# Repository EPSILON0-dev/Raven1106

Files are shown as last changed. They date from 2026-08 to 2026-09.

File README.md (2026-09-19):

# Raven1106

Raspberry Pi-like single board computer based on the Rockchip RV1106G3.

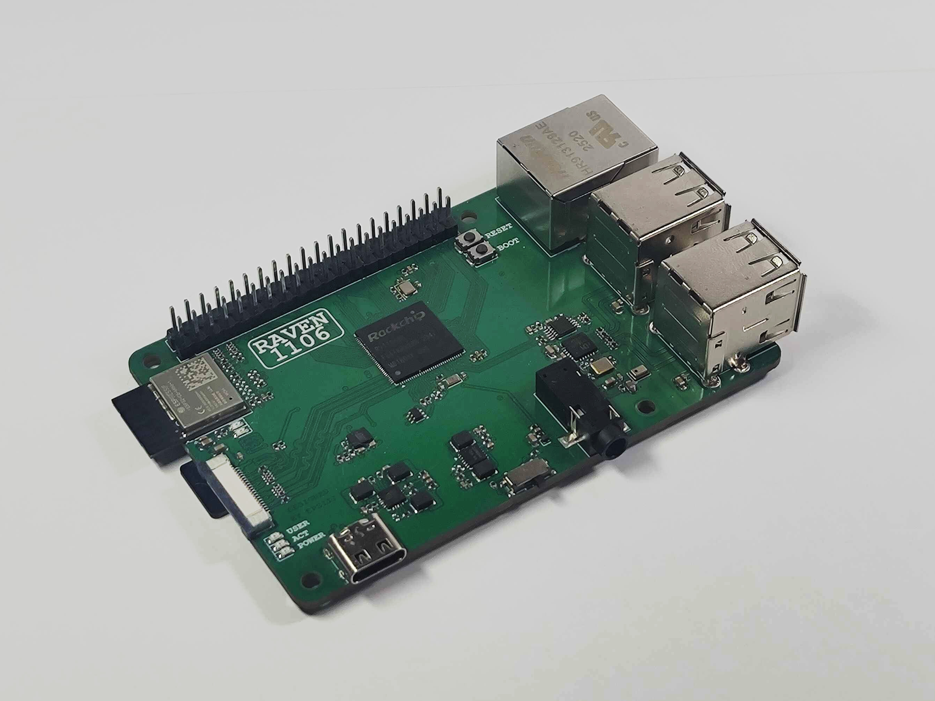
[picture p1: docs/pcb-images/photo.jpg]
Assembled Board Photo


## Overview

Raven1106 is a custom open-hardware SBC. This repository contains everything
related to the project including: the board schematics and the PCB design, build
scripts, configurations, device trees and file system overlays for the 
operating system images and all the patches needed to get everything working.

- CPU: Single-core Cortex-A7 @ 1.6 GHz
- RAM: 256MB DDR3L @ 924MHz
- Storage: SD card
- Ethernet: Full-size 100 MBit/s Ethernet port
- USB: Four USB-A ports routed through CH334F or one OTG USB-C port
- WiFi: ESP32C6 with ESP-Hosted firmware (_currently not functional_)
- Kernel: Linux 5.10 (Rockchip BSP)
- U-Boot: 2017.09 (Rockchip BSP)
- OS images: Debian 12 (bookworm, armhf)

## Why does it exist?

TLDR: It's a learning project

> The main goal of this project was to be a learning experience for designing complex high-speed digital PCBs. Creating an SBC that is almost capable enough to do basic tasks like hosting simple servers or running AI harnesses is a nice bonus. RV1106 was chosen specifically for its simplicity, integrated RAM meant no DDR routing and QFN package meant I could solder the board manually relatively easily. 

> What this chip lacked in the hardware it made up for in the software side of things -- BSP is absolutely terrible, outdated, barely documented (_though with a lot of spelling mistakes_). Programming it wasn't much better either with only a few barely working flashing tools and a USB controller that might not actually be compliant with the USB spec, as most machines can't even enumerate it. It might have been genuinely easier to make this project around a more complex BGA part than this SoC.

## PCB

The board is designed in KiCad (4-layer). `pcb/` contains two revisions:

- `pcb/v1.0` — first revision
- `pcb/v1.1` — revision with component value fixes (no PCB layout changes)

| Layer 1 - Signal | Layer 2 - Ground Plane | Layer 3 - Power Planes | Layer 4 - Signal |
| :-: | :-: | :-: | :-: |
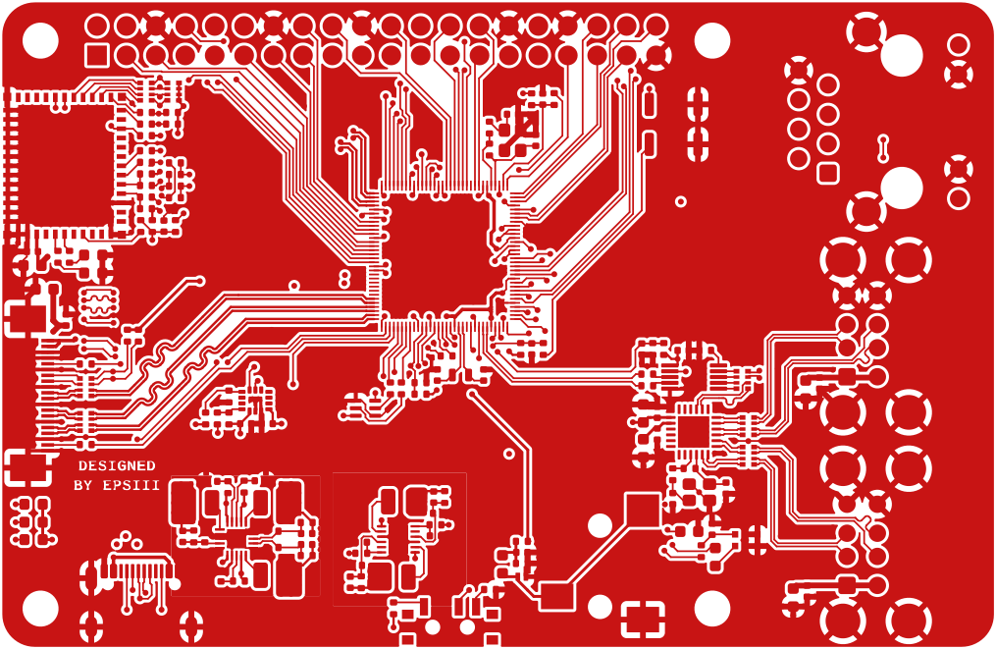
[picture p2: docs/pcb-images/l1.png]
layer1
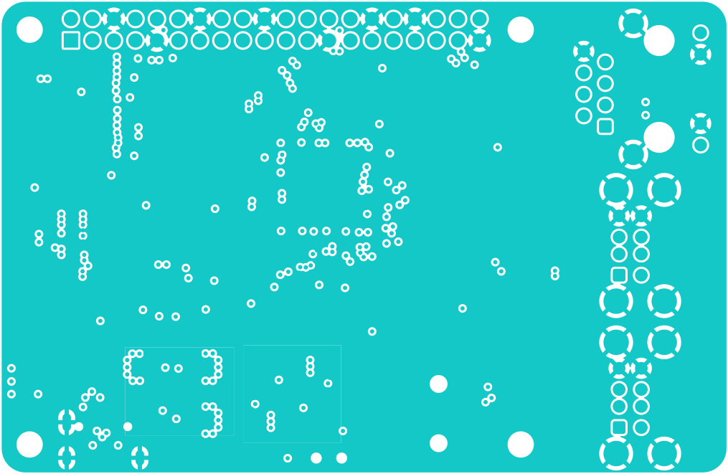
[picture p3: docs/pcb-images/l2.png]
layer2
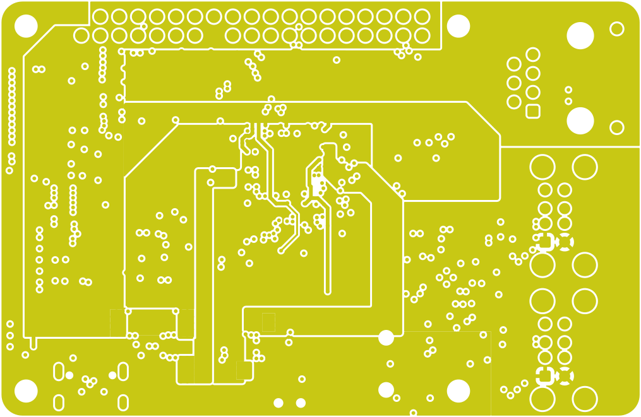
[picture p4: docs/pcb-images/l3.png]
layer3
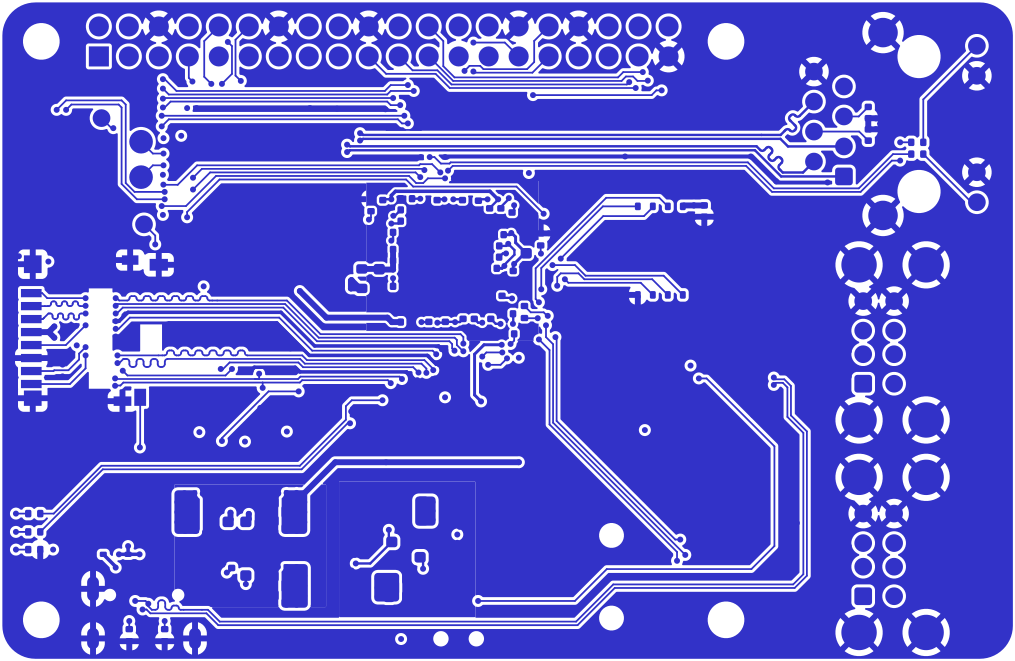
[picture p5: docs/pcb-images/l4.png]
layer4
|  |  |  |  |

### Known v1.0 hardware issues and their fixes

**USB Impedance Miscalculation** - Turns out that FSUSB42MUX doesn't act as a retransmitter but like a normal switch which adds ~10 ohm impedance to the line. **Fix:** Swap `RN301` with 0-ohm and change `R301` and `R302` from 22 ohm to 10 ohm. This results the line impedance that is well in spec.

**No pullups on FSPI Flash** - Speaks for itself, thankfully the RV1106 has internal pull-ups that enable the chip and disable the write protection. And we don't even use it so it's a non-issue. _Cannot fix this without board changes._

**LED resistors too small** - The LEDs shine too brightly with 1k resistors. **Fix:** Change `R3`, `R4` and `R5` from 1k to 10k resistors.

**USB Hub crystal load too large** - The CH334F is designed to work with a crystal with no load caps, adding them causes the oscillation to die down. **Fix:** Change `R309` from 1k to 10 ohm, remove `C302` and `C303`.

**Boot button pull-up too strong** - With 1k the button does not affect the chip's boot at all. **Fix:** Change `R6` from 1k to 10k.

**Wrong ESP_BOOT pin exposed** - It should be pin 9, not pin 8. **Fix:** No way to fix it without modifying the board unfortunately, just flash the bootloader before soldering the ESP.

**Reference clock not connected to the camera** - Turns out not all camera modules have their own crystal oscillators. SC3336 requires a reference clock; RV1106 has two reference clock outputs, one of them is connected to the camera's reset and the other one to the IMU interrupt pin. **Fix:** Add a jumper from `R508` to `R515`.

> Most of these problems could have been prevented with "RTFM" (Reading The F***ing Manual).

## Repository layout

| Path | Contents |
|---|---|
| `configs/` | Defconfigs (kernel, U-Boot, crosstool-ng), device tree source, SD image layout, U-Boot env, user table |
| `kernel/` | Linux 5.10 Rockchip BSP kernel |
| `uboot/` | U-Boot 2017.09 Rockchip BSP |
| `debian/`, `overlayfs/` | Debian rootfs staging area and overlay |
| `crosstool-ng/`, `legacy-toolchain/` | Legacy uClibc toolchain (kernel/U-Boot builds) |
| `esp-hosted/` | ESP32-C6 host driver source (esp_hosted_ng) |
| `rkbin/` | Rockchip binary blobs (DDR init, trust) |
| `scripts/build.sh` | Image assembly, Debian rootfs, Docker environment |
| `images/` | Build artifacts and final `sdcard.img` |
| `pcb/` | KiCad hardware design |
| `docs/` | RV1106 datasheet / reference manuals |

## Building

### Build environment

All builds run inside a Docker container. The first invocation builds the
`rv1106-build` image, then drops you into a shell with the repository
mounted at `/work`:

```sh
make docker
```

### Toolchain

Before building any image build the legacy toolchain for the Kernel and U-Boot.
```sh
make toolchain
```

### Debian image

```sh
make            # default target: debian-image
# or explicitly:
make debian-image
```

> Known issue: If build fails on stage 2 debootstrap because of "Invalid format", just delete the `debian/` directory, restart the container and try to build again. _It does that sometimes..._

This builds the kernel, device tree, and U-Boot, then creates a Debian 12
(bookworm, armhf) rootfs with debootstrap (using qemu-user-static/binfmt for
the second stage) and assembles `images/sdcard.img`.

Notes:

- Default login: user `debian`, password `raven` (sudo user, SSH enabled).
  Override with the `BOARD_USER` and `DEBIAN_PASSWORD` environment variables.
- Included packages: systemd, ifupdown, openssh-server, sudo, dhcp client,
  busybox, vim-tiny, ca-certificates (see `DEBIAN_PACKAGES` in
  `scripts/build.sh`).
- Rootfs image size: 1 GB (`DEBIAN_ROOTFS_SIZE`).
- For now there's no autoresize, run `sudo resize2fs /dev/mmcblk1p5` after
  the first boot.

### Component targets

| Target | Description |
|---|---|
| `make kernel` | Build the kernel using the legacy toolchain |
| `make dtb` | Preprocess and compile `configs/device-tree.dts` into `images/` |
| `make uboot` | Build U-Boot (SPL + idblock + uboot.img) |
| `make espdriver` | Build the ESP32-C6 host driver against the kernel |
| `make toolchain` | Build the crosstool-ng uClibc toolchain |
| `make docker` | Build/enter the Docker build environment |
| `make *-clean` | Clean kernel / U-Boot build trees |

### Configuration targets

Each of these copies the stored defconfig from `configs/`, opens
`menuconfig`, and saves the result back to `configs/`:

```sh
make kernel-config
make uboot-config
make toolchain-config
```

## Output artifacts

All artifacts land in `images/`:

| File | Description |
|---|---|
| `sdcard.img` | Final flashable SD card image |
| `download.bin`, `idblock.img`, `uboot.img` | Bootloader stages |
| `Image`, `zImage`, `device-tree.dtb` | Kernel and device tree |
| `env.img` | U-Boot environment (from `configs/image-env.txt`) |
| `boot.vfat` | FAT32 boot partition (kernel + dtb) |
| `rootfs.ext4`, `rootfs.tar` | Root filesystem |

### SD card layout

The image has no MBR/GPT; partitions are defined by the kernel command line
(`blkdevparts`, see `configs/sdcard-image.cfg` and `configs/image-env.txt`):

| Partition | Offset | Size | Contents |
|---|---|---|---|
| env | 0x0 | 32 KiB | U-Boot environment |
| idblock | 0x8000 | 512 KiB | Rockchip ID block (SPL) |
| uboot | 0x88000 | 256 KiB | U-Boot |
| boot | 4 MiB | 64 MiB | FAT32: kernel image + device tree |
| rootfs | 68 MiB | remainder | ext4 root filesystem |

## Flashing and first boot

```sh
sudo dd if=images/sdcard.img of=/dev/sdX bs=4M status=progress conv=fsync
```

Serial console: `ttyFIQ0` at 115200 baud.

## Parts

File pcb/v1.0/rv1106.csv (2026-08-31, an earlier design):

Reference | Qty | Value | DNP | Footprint | LCSC
C1,C2,C3,C4,C302,C303 | 6 | 18p |  | Capacitor_SMD:C_0402_1005Metric | C7393840
C5 | 1 | 1n |  | Capacitor_SMD:C_0402_1005Metric | C6119789
C6 | 1 | 10n |  | Capacitor_SMD:C_0402_1005Metric | C696856
C101,C106 | 2 | DNP | DNP | Capacitor_SMD:C_0402_1005Metric
C102,C103,C104,C109,C113,C114,C115,C116,C117,C118,C119,C122,C123,C126,C127,C131,C146,C203,C307,C309,C311,C314,C402,C502,C503,C507 | 26 | 10u 6.3V |  | Capacitor_SMD:C_0603_1608Metric | C1691
C105,C107,C108,C124,C125,C129,C130,C132,C133,C134,C135,C136,C137,C138,C139,C140,C141,C142,C143,C144,C145,C147,C149,C150,C152,C154,C156,C157,C158,C202,C301,C304,C305,C306,C308,C310,C312,C313,C403,C501,C504,C505,C506 | 43 | 100n |  | Capacitor_SMD:C_0402_1005Metric | C3839219
C110,C111,C112,C120,C121 | 5 | 220p |  | Capacitor_SMD:C_0402_1005Metric | C50323515
C128,C153,C401,C508 | 4 | 1u |  | Capacitor_SMD:C_0402_1005Metric | C380293
C201 | 1 | 100n | DNP | Capacitor_SMD:C_0402_1005Metric | C3839219
D1 | 1 | POWER |  | LED_SMD:LED_0603_1608Metric
D2 | 1 | ACT |  | LED_SMD:LED_0603_1608Metric
D3 | 1 | USER |  | LED_SMD:LED_0603_1608Metric
D201 | 1 | BAT60A |  | Diode_SMD:D_SOD-323 | C5355496
D401 | 1 | ESP_LED0 |  | LED_SMD:LED_0603_1608Metric
D402 | 1 | ESP_LED1 |  | LED_SMD:LED_0603_1608Metric
D501 | 1 | PESD3V3S1UL |  | Diode_SMD:D_SOD-882 | C70371
J1 | 1 | GPIO |  | Connector_PinHeader_2.54mm:PinHeader_2x20_P2.54mm_Vertical
J201 | 1 | Micro_SD_Card_Det1 |  | Connector_Card:microSD_HC_Hirose_DM3D-SF | C719027
J301 | 1 | USB_C_Receptacle_USB2.0_14P |  | Connector_USB:USB_C_Receptacle_G-Switch_GT-USB-7010ASV
J302 | 1 | HR913129AE |  | Connector_RJ:RJ45_Hanrun_HR911105A_Horizontal | C95663
J303,J304 | 2 | USB_A_Stacked |  | Connector_USB:USB_A_Wuerth_61400826021_Horizontal_Stacked | C456021
J501 | 1 | AudioJack |  | Connector_Audio:Jack_3.5mm_CUI_SJ-3523-SMT_Horizontal | C4991872
J502 | 1 | Camera |  | FPC_Connector:FPC_20_0.5mm_MP_BottomSide | C51364851
L101,L102,L103,L104,L105 | 5 | 1u5 |  | Inductor_SMD:L_1008_2520Metric | C53514831
MIC501 | 1 | MSM421ACT006 |  | Microphone:LGA4-1.9x2.8 | C51928207
Q501 | 1 | FDG1024NZ |  | Package_TO_SOT_SMD:SOT-363_SC-70-6 | C51886163
R1 | 1 | 1M |  | Resistor_SMD:R_0402_1005Metric | C3017524
R2,R205,R301,R302,R412,R413,R416,R417,R418,R419,R508,R515,R516 | 13 | 22 |  | Resistor_SMD:R_0402_1005Metric | C2929994
R3,R4,R5,R6,R8,R303,R307,R308,R309,R311,R312,R403 | 12 | 1k |  | Resistor_SMD:R_0402_1005Metric | C54531013
R7,R9,R402,R404,R503,R505,R509 | 7 | 100 |  | Resistor_SMD:R_0402_1005Metric | C54920716
R101,R103,R201,R313,R401,R406,R407,R420,R421,R501,R507,R510,R511,R512,R513 | 15 | 10k |  | Resistor_SMD:R_0402_1005Metric | C54531014
R102,R104 | 2 | 100k |  | Resistor_SMD:R_0402_1005Metric | C53224176
R105 | 1 | 200k |  | Resistor_SMD:R_0402_1005Metric | C54920643
R106,R107,R112,R113 | 4 | 100k 1% |  | Resistor_SMD:R_0402_1005Metric | C53224176
R108 | 1 | 9.1k 1% |  | Resistor_SMD:R_0402_1005Metric | C54920711
R109,R114 | 2 | 47k 1% |  | Resistor_SMD:R_0402_1005Metric | C18222281
R110 | 1 | 200k 1% |  | Resistor_SMD:R_0402_1005Metric | C54920643
R111 | 1 | 40.2k 1% |  | Resistor_SMD:R_0402_1005Metric | C25893
R115 | 1 | 127k 1% |  | Resistor_SMD:R_0402_1005Metric | C48391434
R116 | 1 | 240 1% |  | Resistor_SMD:R_0402_1005Metric | C2909339
R117 | 1 | 0 (0603) |  | Resistor_SMD:R_0603_1608Metric | C53224183
R202,R502 | 2 | 0 | DNP | Resistor_SMD:R_0402_1005Metric
R304,R306 | 2 | 5k1 |  | Resistor_SMD:R_0402_1005Metric | C53224182
R305 | 1 | 6.04k 1% |  | Resistor_SMD:R_0402_1005Metric | C881060
R310 | 1 | 1M | DNP | Resistor_SMD:R_0402_1005Metric
R314 | 1 | 18k |  | Resistor_SMD:R_0402_1005Metric | C49653003
R408,R409,R506 | 3 | 10k | DNP | Resistor_SMD:R_0402_1005Metric
R410,R411,R414,R415 | 4 | 22 | DNP | Resistor_SMD:R_0402_1005Metric
RN301,RN302,RN303,RN402,RN501,RN502 | 6 | 22 |  | Resistor_SMD:R_Array_Convex_4x0402 | C168184
RN401 | 1 | 10k |  | Resistor_SMD:R_Array_Convex_4x0402 | C168183
SW1 | 1 | Boot |  | Button_Switch_SMD:SW_Push_SPST_NO_Alps_SKRK
SW2 | 1 | Reset |  | Button_Switch_SMD:SW_Push_SPST_NO_Alps_SKRK
SW301 | 1 | USB_Select |  | Button_Switch_SMD:SW_SPDT_PCM12
TP401 | 1 | ESP_Boot |  | TestPoint:TestPoint_Pad_D1.5mm
TP402 | 1 | ESP_Reset |  | TestPoint:TestPoint_Pad_D1.5mm
TP404 | 1 | ESP_USBM |  | TestPoint:TestPoint_Pad_D2.0mm
TP405 | 1 | ESP_USBP |  | TestPoint:TestPoint_Pad_D2.0mm
U1 | 1 | RV1106G3 |  | library:Rockchip_QFN-128-1EP_12.3x12.3mm_P0.35mm_EP7x7mm
U101 | 1 | EA3036CQB |  | Package_DFN_QFN:QFN-20-1EP_3x3mm_P0.4mm_EP1.65x1.65mm | C570857
U102 | 1 | PAM2306AYPAA |  | Package_DFN_QFN:WDFN-12-1EP_3x3mm_P0.45mm_EP1.7x2.5mm | C508237
U202 | 1 | Flash | DNP | Package_SON:WSON-8-1EP_8x6mm_P1.27mm_EP3.4x4.3mm
U302 | 1 | FSUSB42MUX |  | Package_SO:MSOP-10_3x3mm_P0.5mm | C11355
U303 | 1 | CH334F |  | Package_DFN_QFN:QFN-24-1EP_4x4mm_P0.5mm_EP2.7x2.7mm | C5187527
U402 | 1 | ESP32-C6-MINI-1 |  | RF_Module:ESP32-C6-MINI-1
U501 | 1 | LSM6DSR |  | Package_LGA:LGA-14_3x2.5mm_P0.5mm_LayoutBorder3x4y
Y1 | 1 | 32.768kHz |  | Crystal:Crystal_SMD_2012-2Pin_2.0x1.2mm | C2961989
Y2 | 1 | 24MHz 20ppm |  | Crystal:Crystal_SMD_2520-4Pin_2.5x2.0mm | C5261113
Y301 | 1 | 12MHz |  | Crystal:Crystal_SMD_2520-4Pin_2.5x2.0mm | C5261113

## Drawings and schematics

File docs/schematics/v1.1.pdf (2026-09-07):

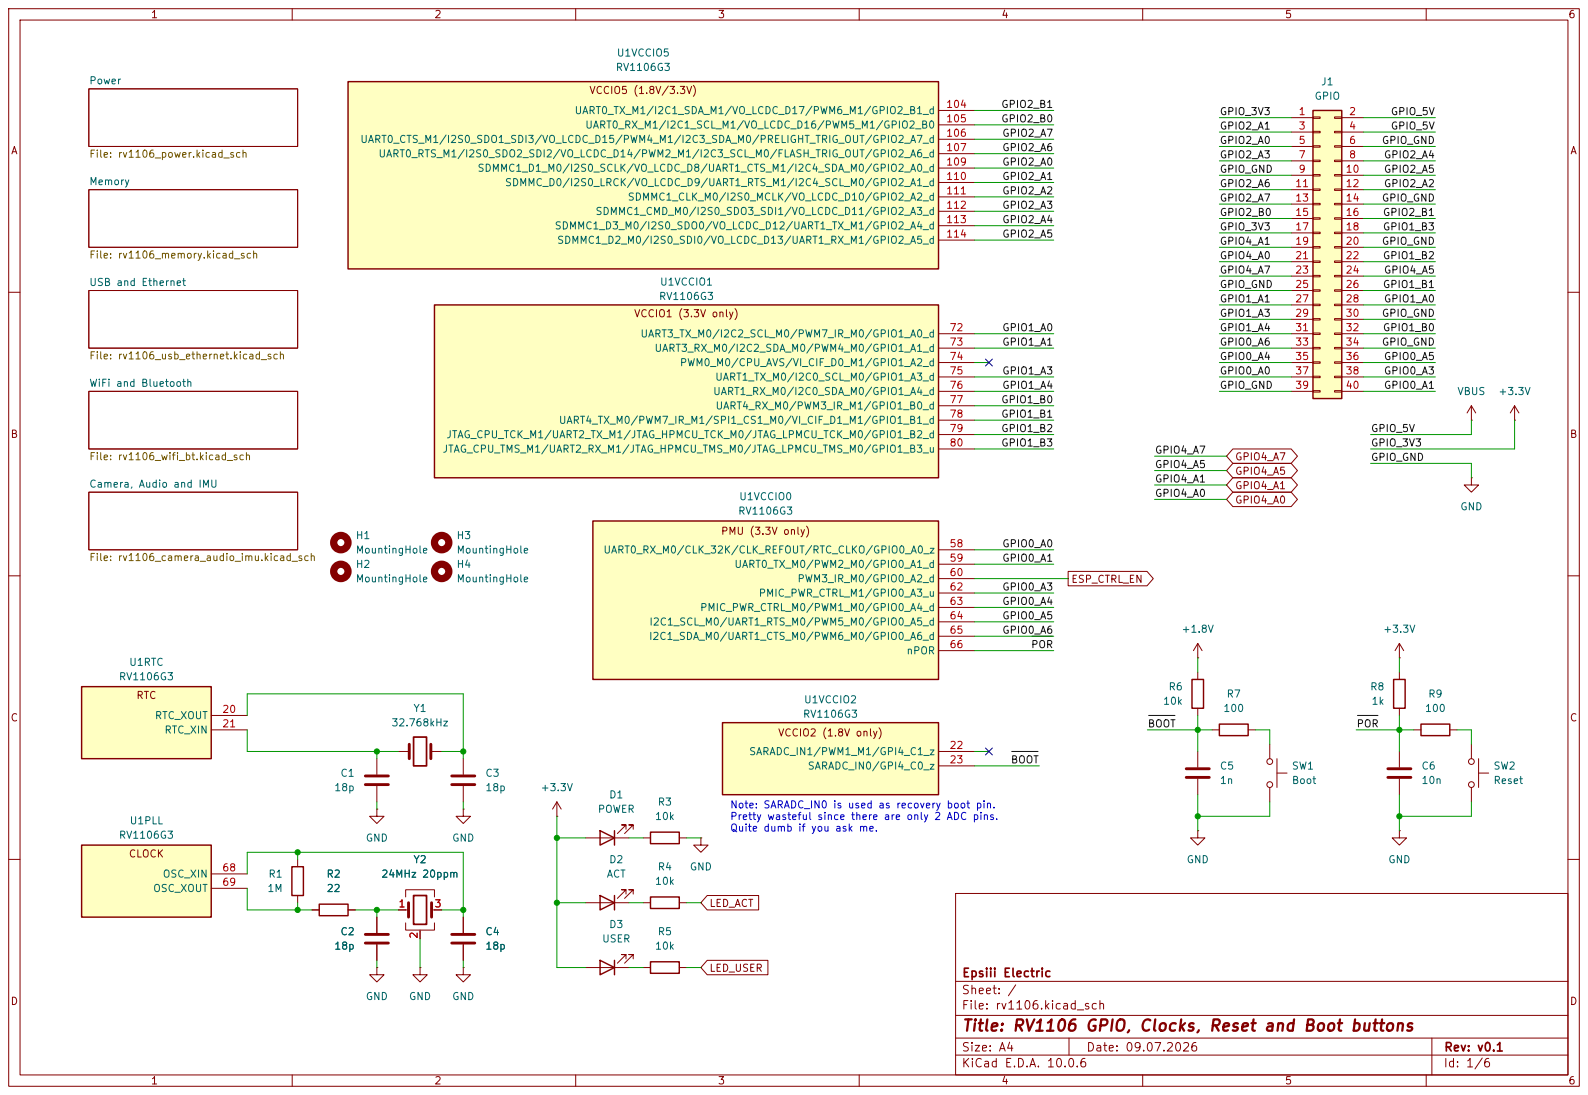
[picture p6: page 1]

File: rv1106_camera_audio_imu.kicad_sch USB and Ethernet File: rv1106_usb_ethernet.kicad_sch Memory File: rv1106_memory.kicad_sch WiFi and Bluetooth

Camera, Audio and IMU

Pretty wasteful since there are only 2 ADC pins. Quite dumb if you ask me. C4

Epsiii Electric
Sheet: /
File: rv1106.kicad_sch
Title: RV1106 GPIO, Clocks, Reset and Boot buttons

Size: A4 | Rev: v0.1
KiCad E.D.A. 10.0.6 | Id: 1/6

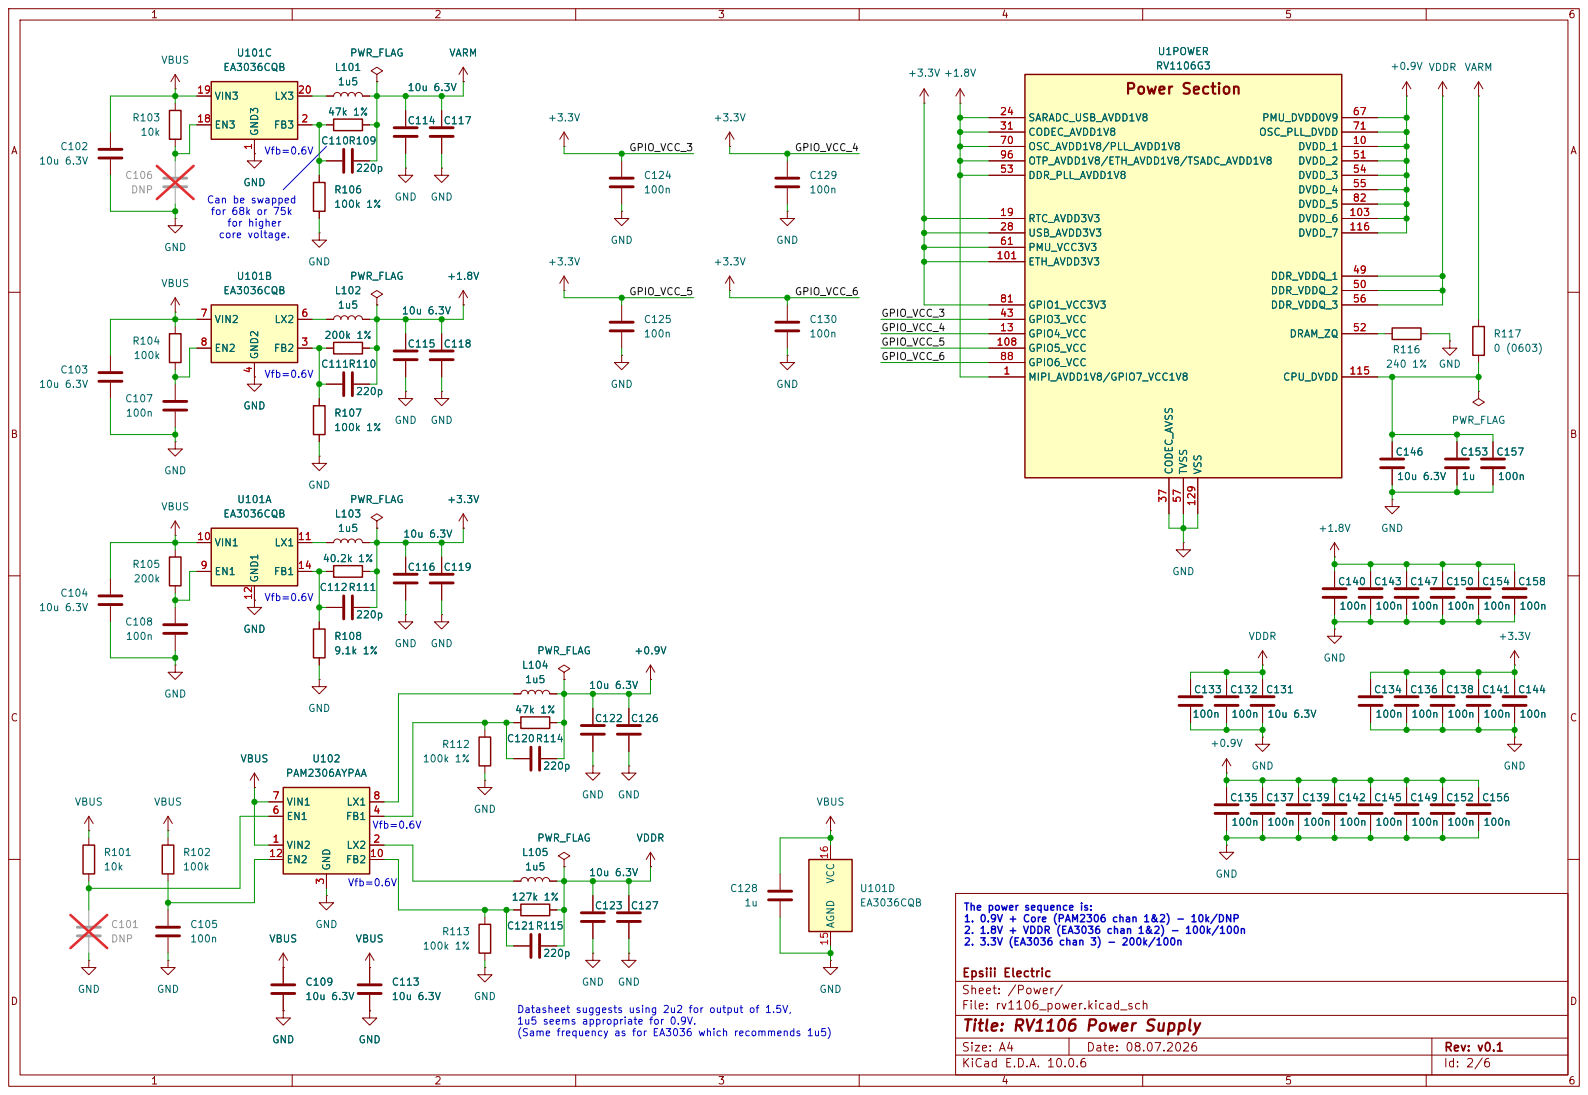
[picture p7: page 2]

Vfb=0.6V Can be swapped

for 68k or 75k
for higher core voltage.

The power sequence is: 1. 0.9V + Core (PAM2306 chan 1&2) - 10k/DNP

2. 1.8V + VDDR (EA3036 chan 1&2) - 100k/100n 2. 3.3V (EA3036 chan 3) - 200k/100n Datasheet suggests using 2u2 for output of 1.5V, 1u5 seems appropriate for 0.9V. (Same frequency as for EA3036 which recommends 1u5)

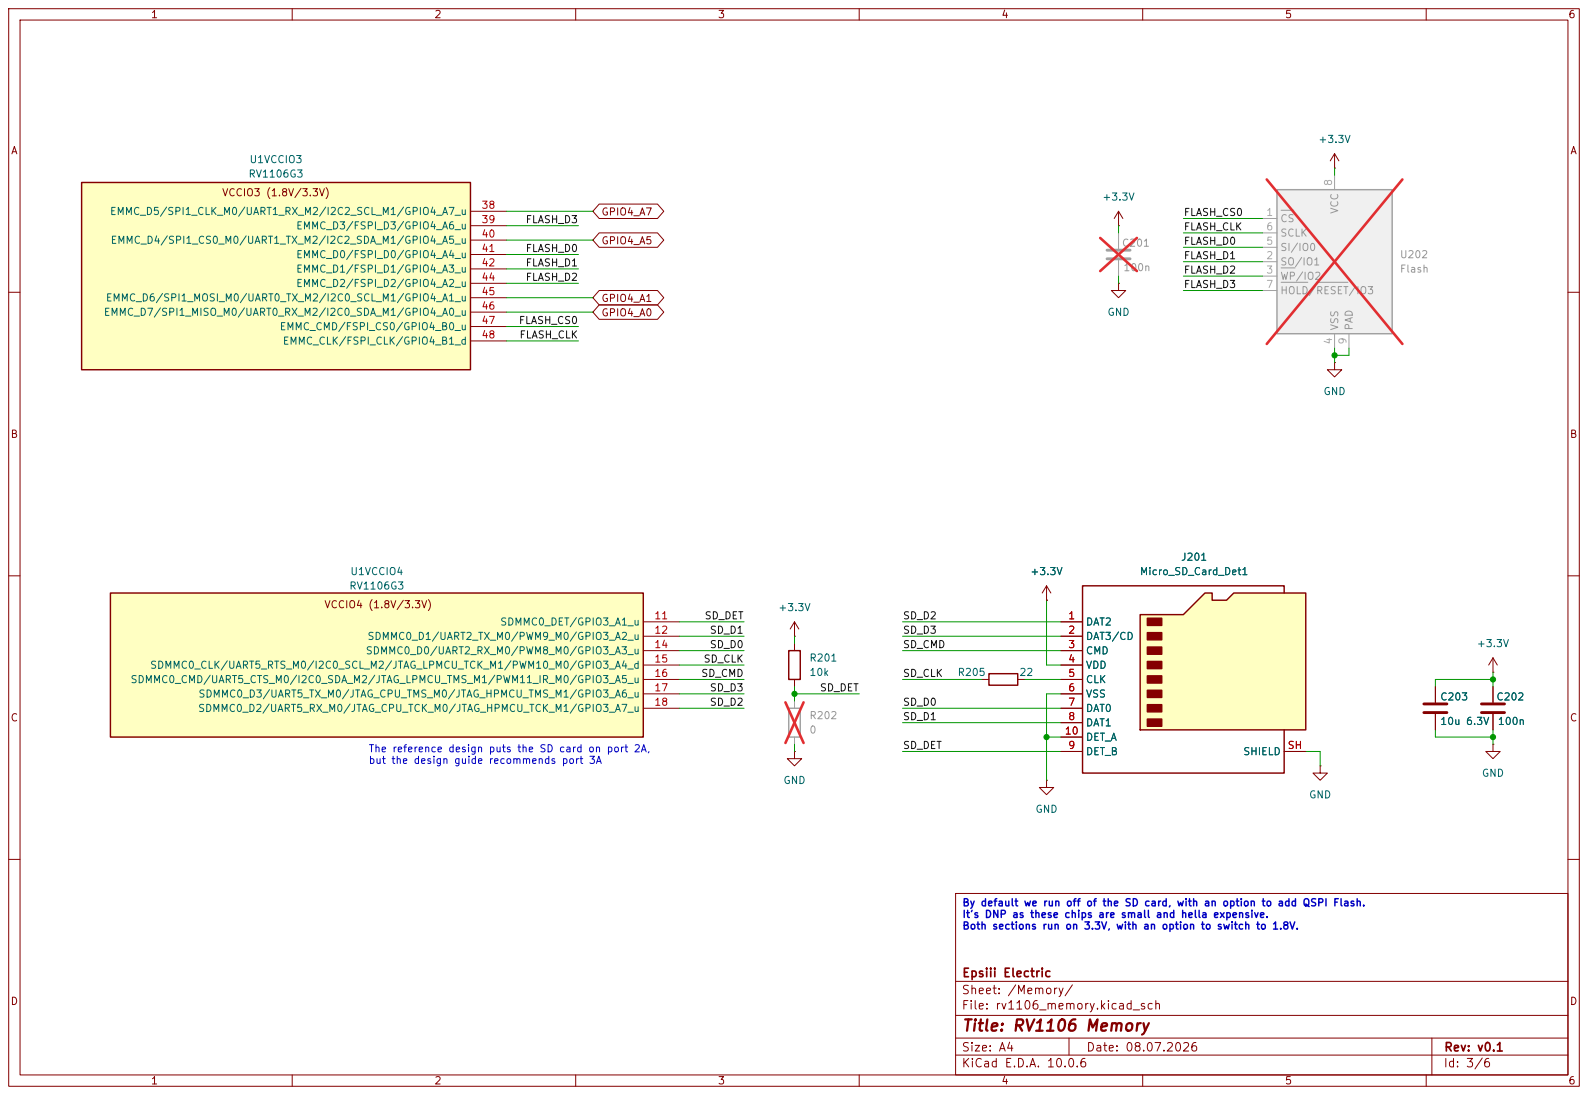
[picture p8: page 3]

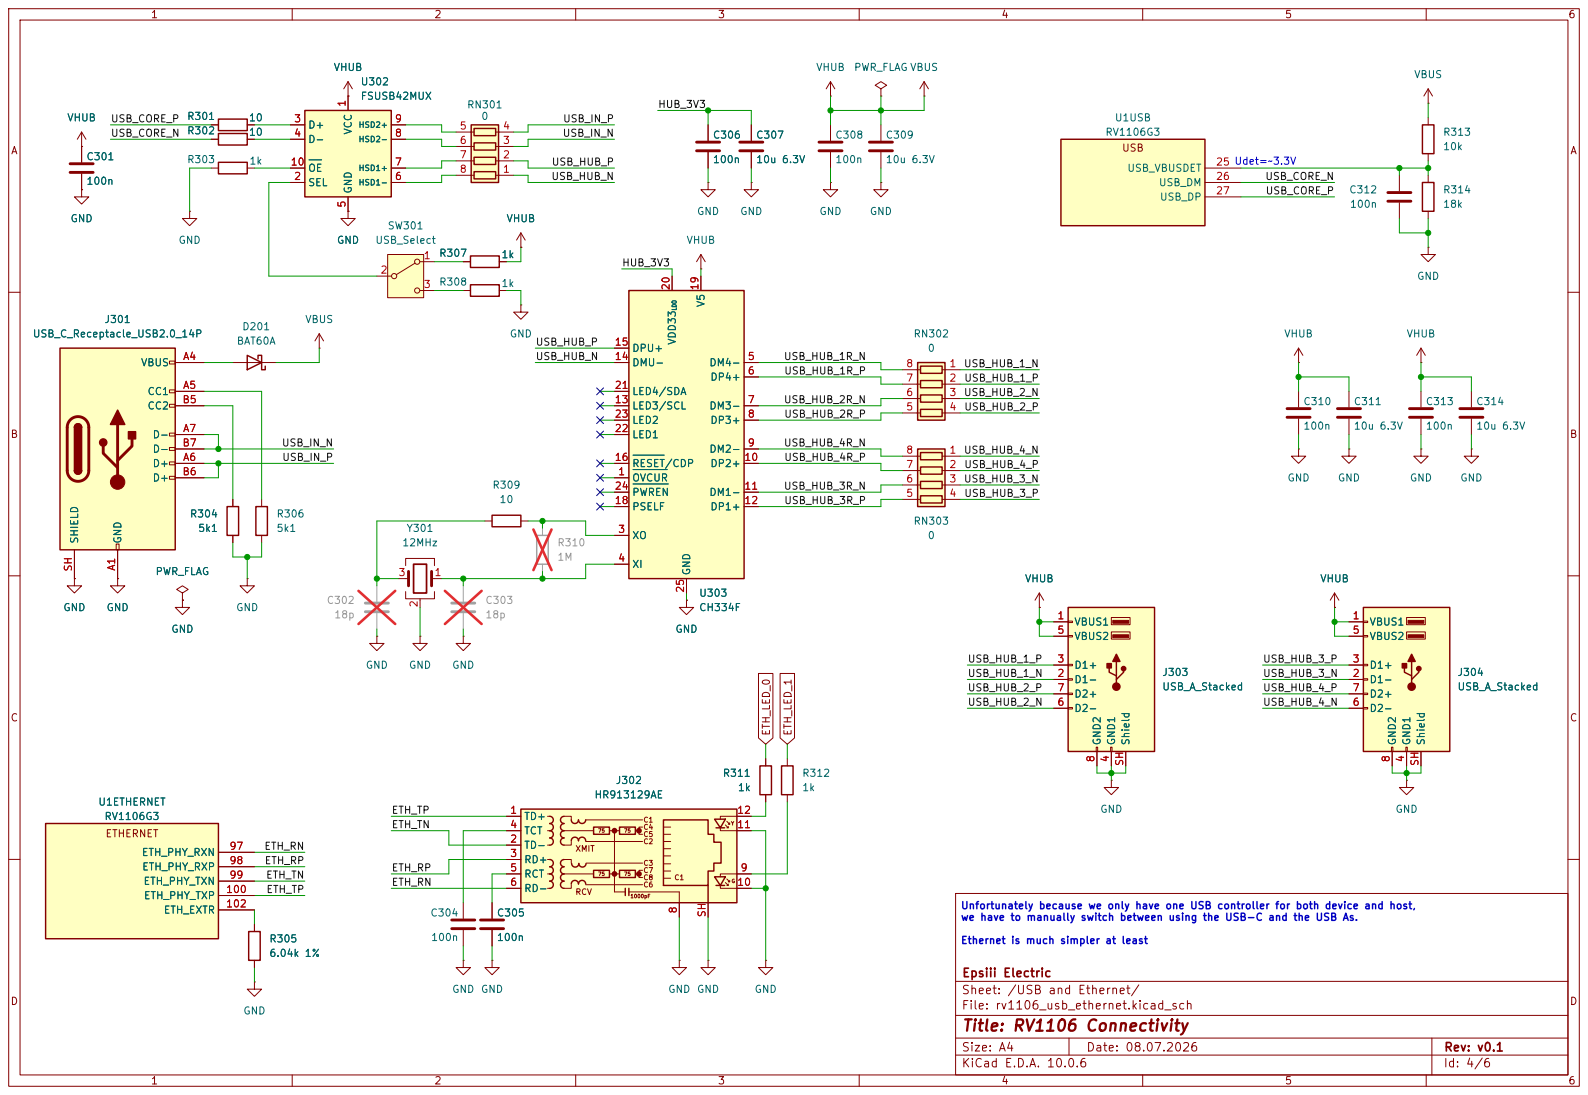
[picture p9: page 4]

Epsiii Electric
Sheet: /USB and Ethernet/
File: rv1106_usb_ethernet.kicad_sch
Title: RV1106 Connectivity

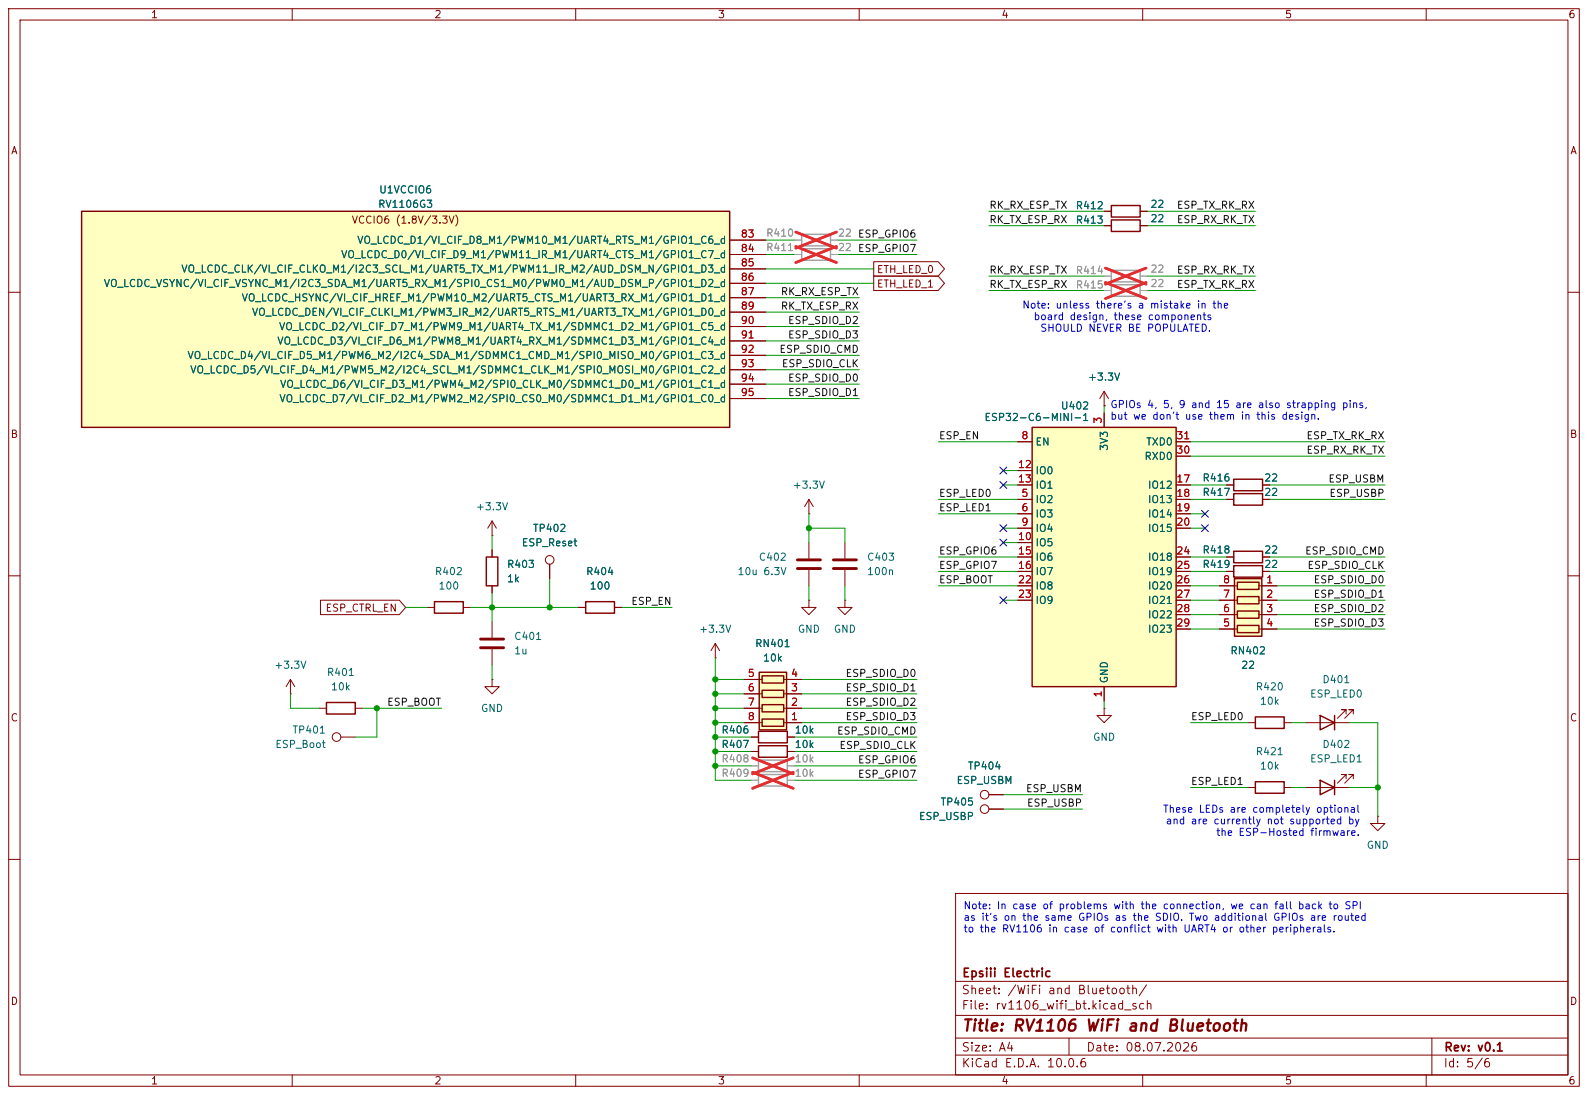
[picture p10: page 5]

to the RV1106 in case of conflict with UART4 or other peripherals. These LEDs are completely optional and are currently not supported by

Epsiii Electric
Sheet: /WiFi and Bluetooth/
File: rv1106_wifi_bt.kicad_sch
Title: RV1106 WiFi and Bluetooth

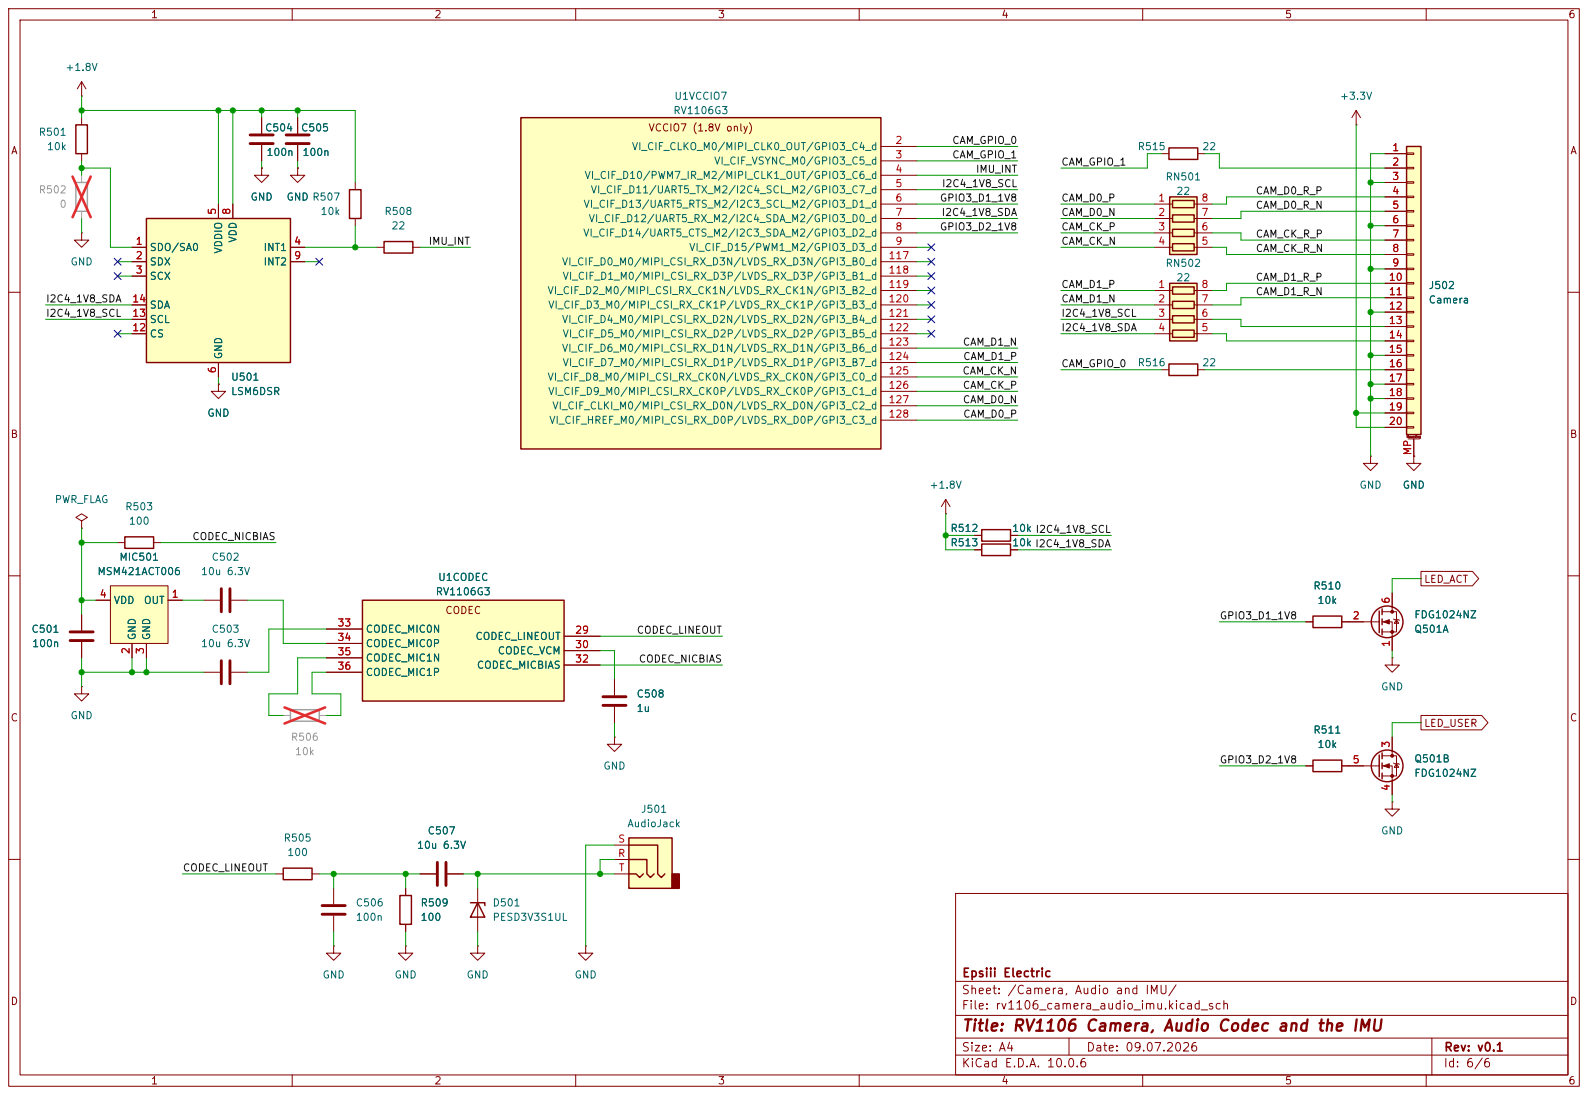
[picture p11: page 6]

Sheet: /Camera, Audio and IMU/
File: rv1106_camera_audio_imu.kicad_sch
Title: RV1106 Camera, Audio Codec and the IMU

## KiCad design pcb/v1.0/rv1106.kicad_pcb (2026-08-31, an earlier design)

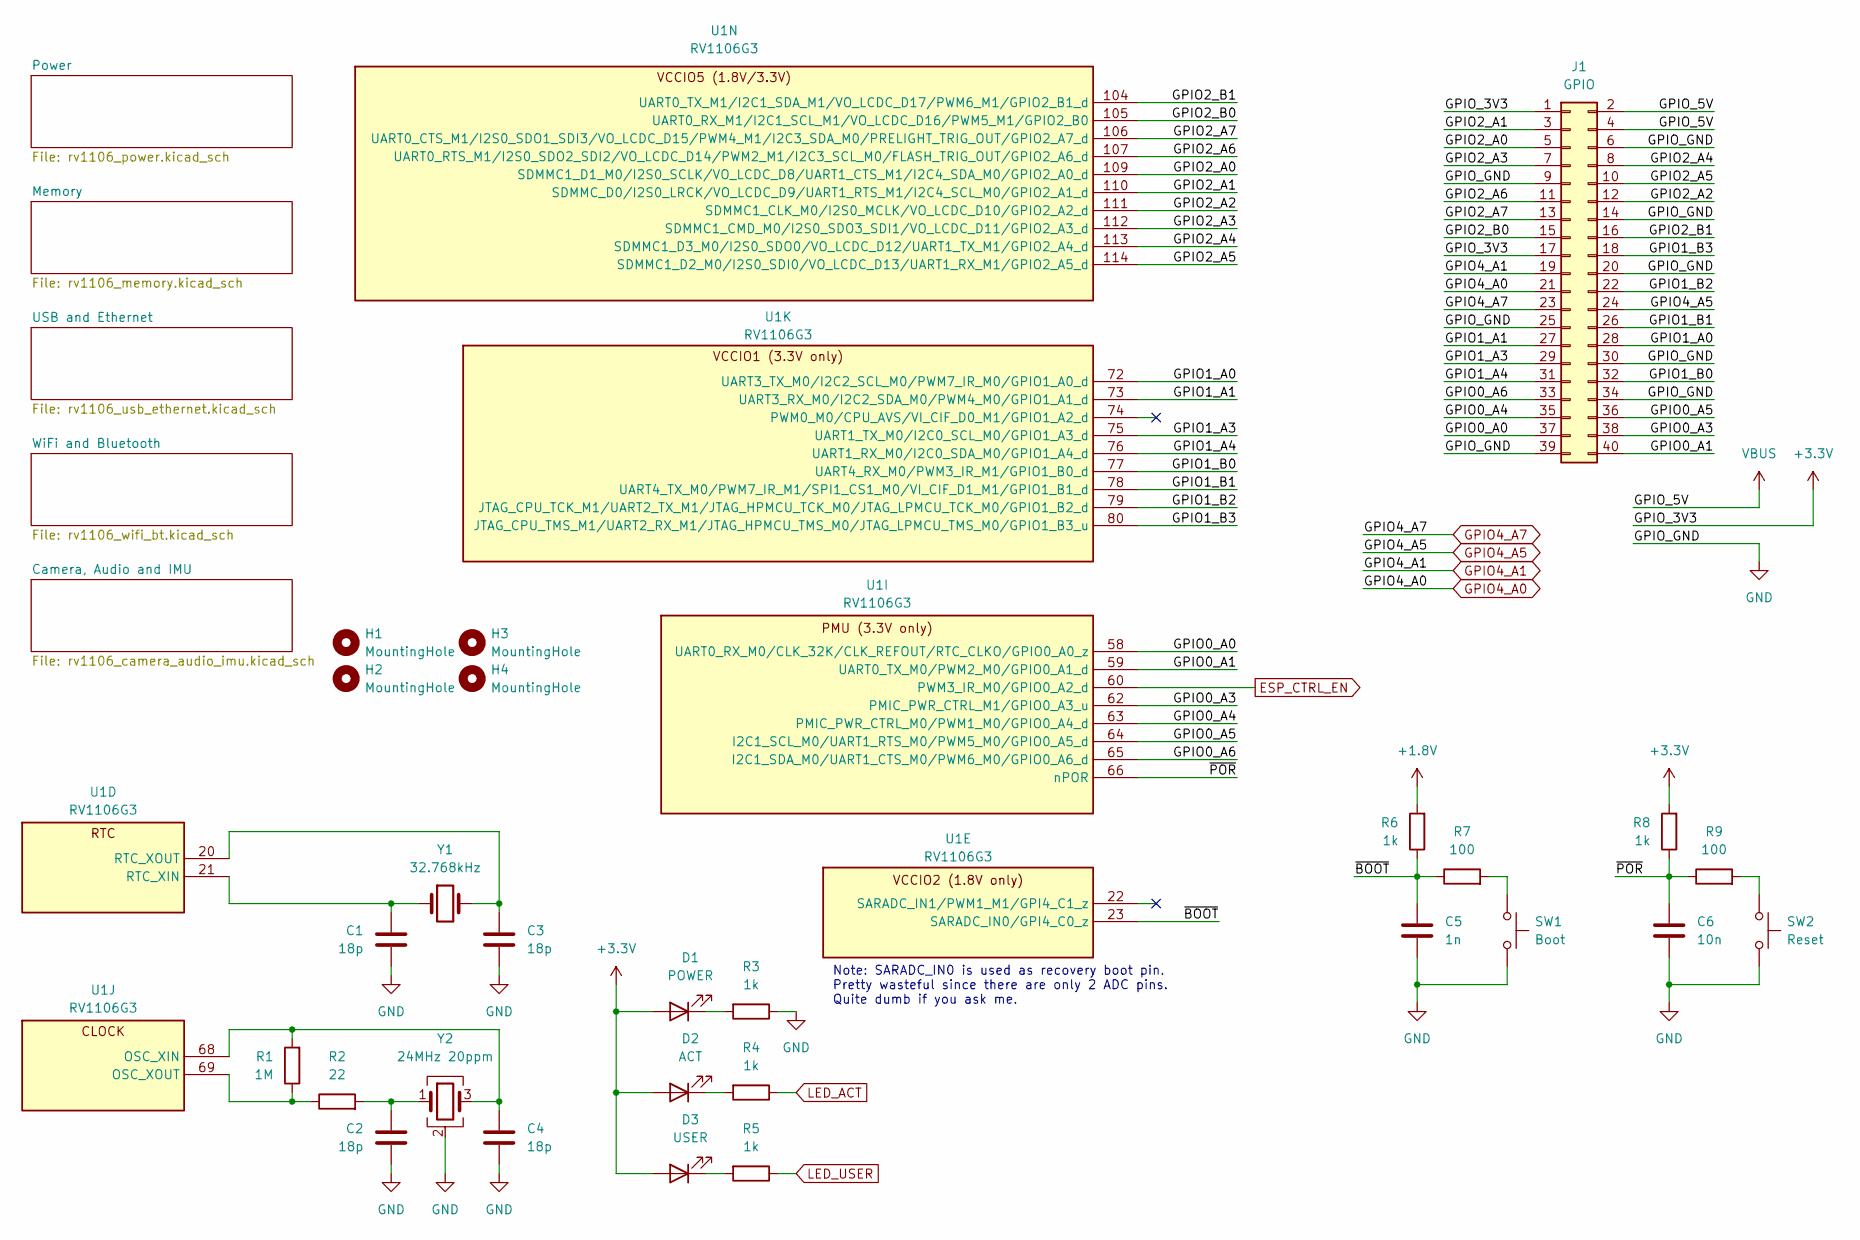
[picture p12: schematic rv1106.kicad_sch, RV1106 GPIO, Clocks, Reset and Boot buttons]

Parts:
C1, C2, C3, C4: 18p; C_0402_1005Metric; LCSC C7393840
C5: 1n; C_0402_1005Metric; LCSC C6119789
C6: 10n; C_0402_1005Metric; LCSC C696856
D1: POWER; LED_0603_1608Metric
D2: ACT; LED_0603_1608Metric
D3: USER; LED_0603_1608Metric
H1, H2, H3, H4: MountingHole; MountingHole_2.7mm_M2.5
J1: GPIO; PinHeader_2x20_P2.54mm_Vertical
R1: 1M; R_0402_1005Metric; LCSC C3017524
R2: 22; R_0402_1005Metric; LCSC C2929994
R3, R4, R5, R6, R8: 1k; R_0402_1005Metric; LCSC C54531013
R7, R9: 100; R_0402_1005Metric; LCSC C54920716
SW1: Boot; SW_Push_SPST_NO_Alps_SKRK
SW2: Reset; SW_Push_SPST_NO_Alps_SKRK
U1: RV1106G3; Rockchip_QFN-128-1EP_12.3x12.3mm_P0.35mm_EP7x7mm
Y1: 32.768kHz; Crystal_SMD_2012-2Pin_2.0x1.2mm; LCSC C2961989
Y2: 24MHz 20ppm; Crystal_SMD_2520-4Pin_2.5x2.0mm; LCSC C5261113

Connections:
+1.8V: R6.2; also elsewhere on the board
+3.3V: D1.2 (A), D2.2 (A), D3.2 (A), J1.1, J1.17, R8.2; also elsewhere on the board
/GPIO0_A0: J1.37, U1.58 (UART0_RX_M0/CLK_32K/CLK_REFOUT/RTC_CLKO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)
/GPIO0_A1: J1.40, U1.59 (UART0_TX_M0/PWM2_M0/GPIO0_A1_d)
/GPIO0_A3: J1.38, U1.62 (PMIC_PWR_CTRL_M1/GPIO0_A3_u)
/GPIO0_A4: J1.35, U1.63 (PMIC_PWR_CTRL_M0/PWM1_M0/GPIO0_A4_d)
/GPIO0_A5: J1.36, U1.64 (I2C1_SCL_M0/UART1_RTS_M0/PWM5_M0/GPIO0_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)
/GPIO0_A6: J1.33, U1.65 (I2C1_SDA_M0/UART1_CTS_M0/PWM6_M0/GPIO0_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)
/GPIO1_A0: J1.28, U1.72 (UART3_TX_M0/I2C2_SCL_M0/PWM7_IR_M0/GPIO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)
/GPIO1_A1: J1.27, U1.73 (UART3_RX_M0/I2C2_SDA_M0/PWM4_M0/GPIO1_A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)
/GPIO1_A3: J1.29, U1.75 (UART1_TX_M0/I2C0_SCL_M0/GPIO1_A3_d)
/GPIO1_A4: J1.31, U1.76 (UART1_RX_M0/I2C0_SDA_M0/GPIO1_A4_d)
/GPIO1_B0: J1.32, U1.77 (UART4_RX_M0/PWM3_IR_M1/GPIO1_B0_d)
/GPIO1_B1: J1.26, U1.78 (UART4_TX_M0/PWM7_IR_M1/SPI1_CS1_M0/VI_C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)
/GPIO1_B2: J1.22, U1.79 (JTAG_CPU_TCK_M1/UART2_TX_M1/JTAG_HPMCU_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)
/GPIO1_B3: J1.18, U1.80 (JTAG_CPU_TMS_M1/UART2_RX_M1/JTAG_HPMCU_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)
/GPIO2_A0: J1.5, U1.109 (SDMMC1_D1_M0/I2S0_SCLK/VO_LCDC_D8/UART1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)
/GPIO2_A1: J1.3, U1.110 (SDMMC_D0/I2S0_LRCK/VO_LCDC_D9/UART1_RTS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)
/GPIO2_A2: J1.12, U1.111 (SDMMC1_CLK_M0/I2S0_MCLK/VO_LCDC_D10/GPI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)
/GPIO2_A3: J1.7, U1.112 (SDMMC1_CMD_M0/I2S0_SDO3_SDI1/VO_LCDC_D1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)
/GPIO2_A4: J1.8, U1.113 (SDMMC1_D3_M0/I2S0_SDO0/VO_LCDC_D12/UART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)
/GPIO2_A5: J1.10, U1.114 (SDMMC1_D2_M0/I2S0_SDI0/VO_LCDC_D13/UART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)
/GPIO2_A6: J1.11, U1.107 (UART0_RTS_M1/I2S0_SDO2_SDI2/VO_LCDC_D14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)
/GPIO2_A7: J1.13, U1.106 (UART0_CTS_M1/I2S0_SDO1_SDI3/VO_LCDC_D15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)
/GPIO2_B0: J1.15, U1.105 (UART0_RX_M1/I2C1_SCL_M1/VO_LCDC_D16/PWM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)
/GPIO2_B1: J1.16, U1.104 (UART0_TX_M1/I2C1_SDA_M1/VO_LCDC_D17/PWM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)
/~BOOT: C5.1, R6.1, R7.1, U1.23 (SARADC_IN0/GPI4_C0_z)
/~POR: C6.1, R8.1, R9.1, U1.66 (nPOR)
ESP_CTRL_EN: U1.60 (PWM3_IR_M0/GPIO0_A2_d); also elsewhere on the board
GND: C1.2, C2.2, C3.2, C4.2, C5.2, C6.2, J1.6, J1.9, J1.14, J1.20, J1.25, J1.30, J1.34, J1.39, R3.1, SW1.2, SW2.2, Y2.2 (G), Y2.4 (G); also elsewhere on the board
GPIO4_A0: J1.21; also elsewhere on the board
GPIO4_A1: J1.19; also elsewhere on the board
GPIO4_A5: J1.24; also elsewhere on the board
GPIO4_A7: J1.23; also elsewhere on the board
LED_ACT: R4.1; also elsewhere on the board
LED_USER: R5.1; also elsewhere on the board
unnamed: C2.1, R2.2, Y2.1
unnamed: D1.1 (K), R3.2
unnamed: D2.1 (K), R4.2
unnamed: D3.1 (K), R5.2
unnamed: R7.2, SW1.1
unnamed: R9.2, SW2.1
unnamed: C1.1, U1.21 (RTC_XIN), Y1.1
unnamed: C3.1, U1.20 (RTC_XOUT), Y1.2
unnamed: C4.1, R1.2, U1.68 (OSC_XIN), Y2.3
unnamed: R1.1, R2.1, U1.69 (OSC_XOUT)
VBUS: J1.2, J1.4; also elsewhere on the board

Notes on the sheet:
Note: SARADC_IN0 is used as recovery boot pin. Pretty wasteful since there are only 2 ADC pins. Quite dumb if you ask me.

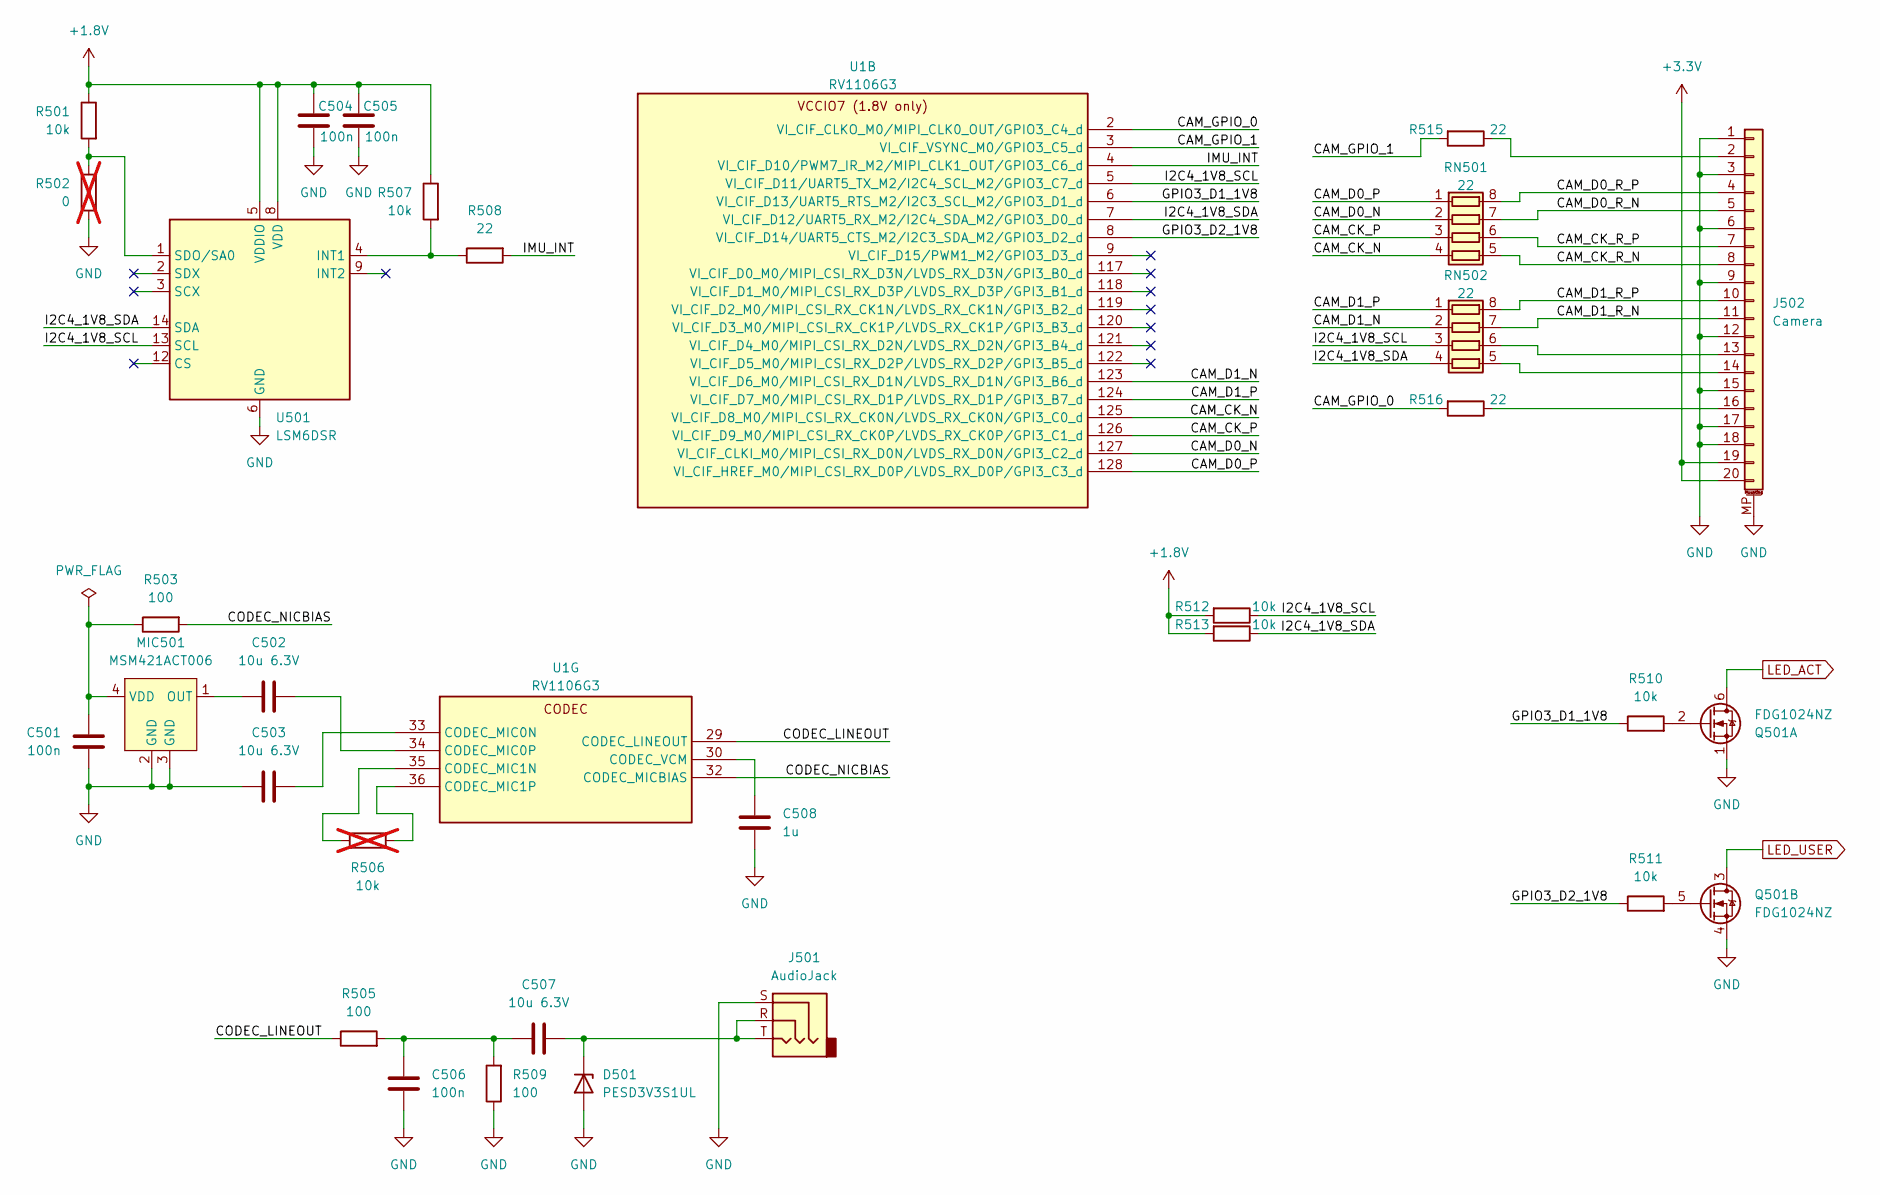
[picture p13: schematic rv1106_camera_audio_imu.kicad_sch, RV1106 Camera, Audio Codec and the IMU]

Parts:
C501, C504, C505, C506: 100n; C_0402_1005Metric; LCSC C3839219
C502, C503, C507: 10u 6.3V; C_0603_1608Metric; LCSC C1691
C508: 1u; C_0402_1005Metric; LCSC C380293
D501: PESD3V3S1UL; D_SOD-882; LCSC C70371
J501: AudioJack; Jack_3.5mm_CUI_SJ-3523-SMT_Horizontal; LCSC C4991872
J502: Camera; FPC_20_0.5mm_MP_BottomSide; LCSC C51364851
MIC501: MSM421ACT006; LGA4-1.9x2.8; LCSC C51928207
Q501: FDG1024NZ; SOT-363_SC-70-6; LCSC C51886163
R501, R507, R510, R511, R512, R513: 10k; R_0402_1005Metric; LCSC C54531014
R502: 0; R_0402_1005Metric; not fitted
R503, R505, R509: 100; R_0402_1005Metric; LCSC C54920716
R506: 10k; R_0402_1005Metric; not fitted
R508, R515, R516: 22; R_0402_1005Metric; LCSC C2929994
RN501, RN502: 22; R_Array_Convex_4x0402; LCSC C168184
U1: RV1106G3; Rockchip_QFN-128-1EP_12.3x12.3mm_P0.35mm_EP7x7mm
U501: LSM6DSR; LGA-14_3x2.5mm_P0.5mm_LayoutBorder3x4y

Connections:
+1.8V: C504.1, C505.1, R501.1, R507.1, R512.2, R513.2, U501.5 (VDDIO), U501.8 (VDD); also elsewhere on the board
+3.3V: J502.19, J502.20; also elsewhere on the board
/Camera, Audio and IMU/CAM_CK_N: RN501.4 (R4.1), U1.125 (VI_CIF_D8_M0/MIPI_CSI_RX_CK0N/LVDS_RX_C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)
/Camera, Audio and IMU/CAM_CK_P: RN501.3 (R3.1), U1.126 (VI_CIF_D9_M0/MIPI_CSI_RX_CK0P/LVDS_RX_C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)
/Camera, Audio and IMU/CAM_CK_R_N: J502.8, RN501.5 (R4.2)
/Camera, Audio and IMU/CAM_CK_R_P: J502.7, RN501.6 (R3.2)
/Camera, Audio and IMU/CAM_D0_N: RN501.2 (R2.1), U1.127 (VI_CIF_CLKI_M0/MIPI_CSI_RX_D0N/LVDS_RX_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)
/Camera, Audio and IMU/CAM_D0_P: RN501.1 (R1.1), U1.128 (VI_CIF_HREF_M0/MIPI_CSI_RX_D0P/LVDS_RX_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)
/Camera, Audio and IMU/CAM_D0_R_N: J502.5, RN501.7 (R2.2)
/Camera, Audio and IMU/CAM_D0_R_P: J502.4, RN501.8 (R1.2)
/Camera, Audio and IMU/CAM_D1_N: RN502.2 (R2.1), U1.123 (VI_CIF_D6_M0/MIPI_CSI_RX_D1N/LVDS_RX_D1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)
/Camera, Audio and IMU/CAM_D1_P: RN502.1 (R1.1), U1.124 (VI_CIF_D7_M0/MIPI_CSI_RX_D1P/LVDS_RX_D1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)
/Camera, Audio and IMU/CAM_D1_R_N: J502.11, RN502.7 (R2.2)
/Camera, Audio and IMU/CAM_D1_R_P: J502.10, RN502.8 (R1.2)
/Camera, Audio and IMU/CAM_GPIO_0: R516.2, U1.2 (VI_CIF_CLKO_M0/MIPI_CLK0_OUT/GPIO3_C4_d)
/Camera, Audio and IMU/CAM_GPIO_1: R515.2, U1.3 (VI_CIF_VSYNC_M0/GPIO3_C5_d)
/Camera, Audio and IMU/CODEC_LINEOUT: R505.1, U1.29 (CODEC_LINEOUT)
/Camera, Audio and IMU/CODEC_NICBIAS: R503.2, U1.32 (CODEC_MICBIAS)
/Camera, Audio and IMU/GPIO3_D1_1V8: R510.1, U1.6 (VI_CIF_D13/UART5_RTS_M2/I2C3_SCL_M2/GPI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)
/Camera, Audio and IMU/GPIO3_D2_1V8: R511.1, U1.8 (VI_CIF_D14/UART5_CTS_M2/I2C3_SDA_M2/GPI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)
/Camera, Audio and IMU/I2C4_1V8_SCL: R512.1, RN502.3 (R3.1), U1.5 (VI_CIF_D11/UART5_TX_M2/I2C4_SCL_M2/GPIO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), U501.13 (SCL)
/Camera, Audio and IMU/I2C4_1V8_SDA: R513.1, RN502.4 (R4.1), U1.7 (VI_CIF_D12/UART5_RX_M2/I2C4_SDA_M2/GPIO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), U501.14 (SDA)
/Camera, Audio and IMU/IMU_INT: R508.2, U1.4 (VI_CIF_D10/PWM7_IR_M2/MIPI_CLK1_OUT/GPI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)
GND: C501.2, C503.1, C504.2, C505.2, C506.2, C508.1, D501.2 (A), J501.S, J502.1, J502.3, J502.6, J502.9, J502.12, J502.15, J502.17, J502.18, J502.MP (MountPin), MIC501.2 (GND), MIC501.3 (GND), Q501.1 (S), Q501.4 (S), R502.2, R509.1, U501.6 (GND), U501.7 (GND); also elsewhere on the board
LED_ACT: Q501.6 (D); also elsewhere on the board
LED_USER: Q501.3 (D); also elsewhere on the board
unnamed: C506.1, C507.1, R505.2, R509.2
unnamed: C507.2, D501.1 (K), J501.R, J501.T
unnamed: J502.2, R515.1
unnamed: J502.13, RN502.6 (R3.2)
unnamed: J502.14, RN502.5 (R4.2)
unnamed: J502.16, R516.1
unnamed: C502.1, MIC501.1 (OUT)
unnamed: C501.1, MIC501.4 (VDD), R503.1
unnamed: Q501.2 (G), R510.2
unnamed: Q501.5 (G), R511.2
unnamed: C503.2, U1.33 (CODEC_MIC0N)
unnamed: C502.2, U1.34 (CODEC_MIC0P)
unnamed: R506.1, U1.35 (CODEC_MIC1N)
unnamed: R506.2, U1.36 (CODEC_MIC1P)
unnamed: C508.2, U1.30 (CODEC_VCM)
unnamed: R507.2, R508.1, U501.4 (INT1)
unnamed: R501.2, R502.1, U501.1 (SDO/SA0)

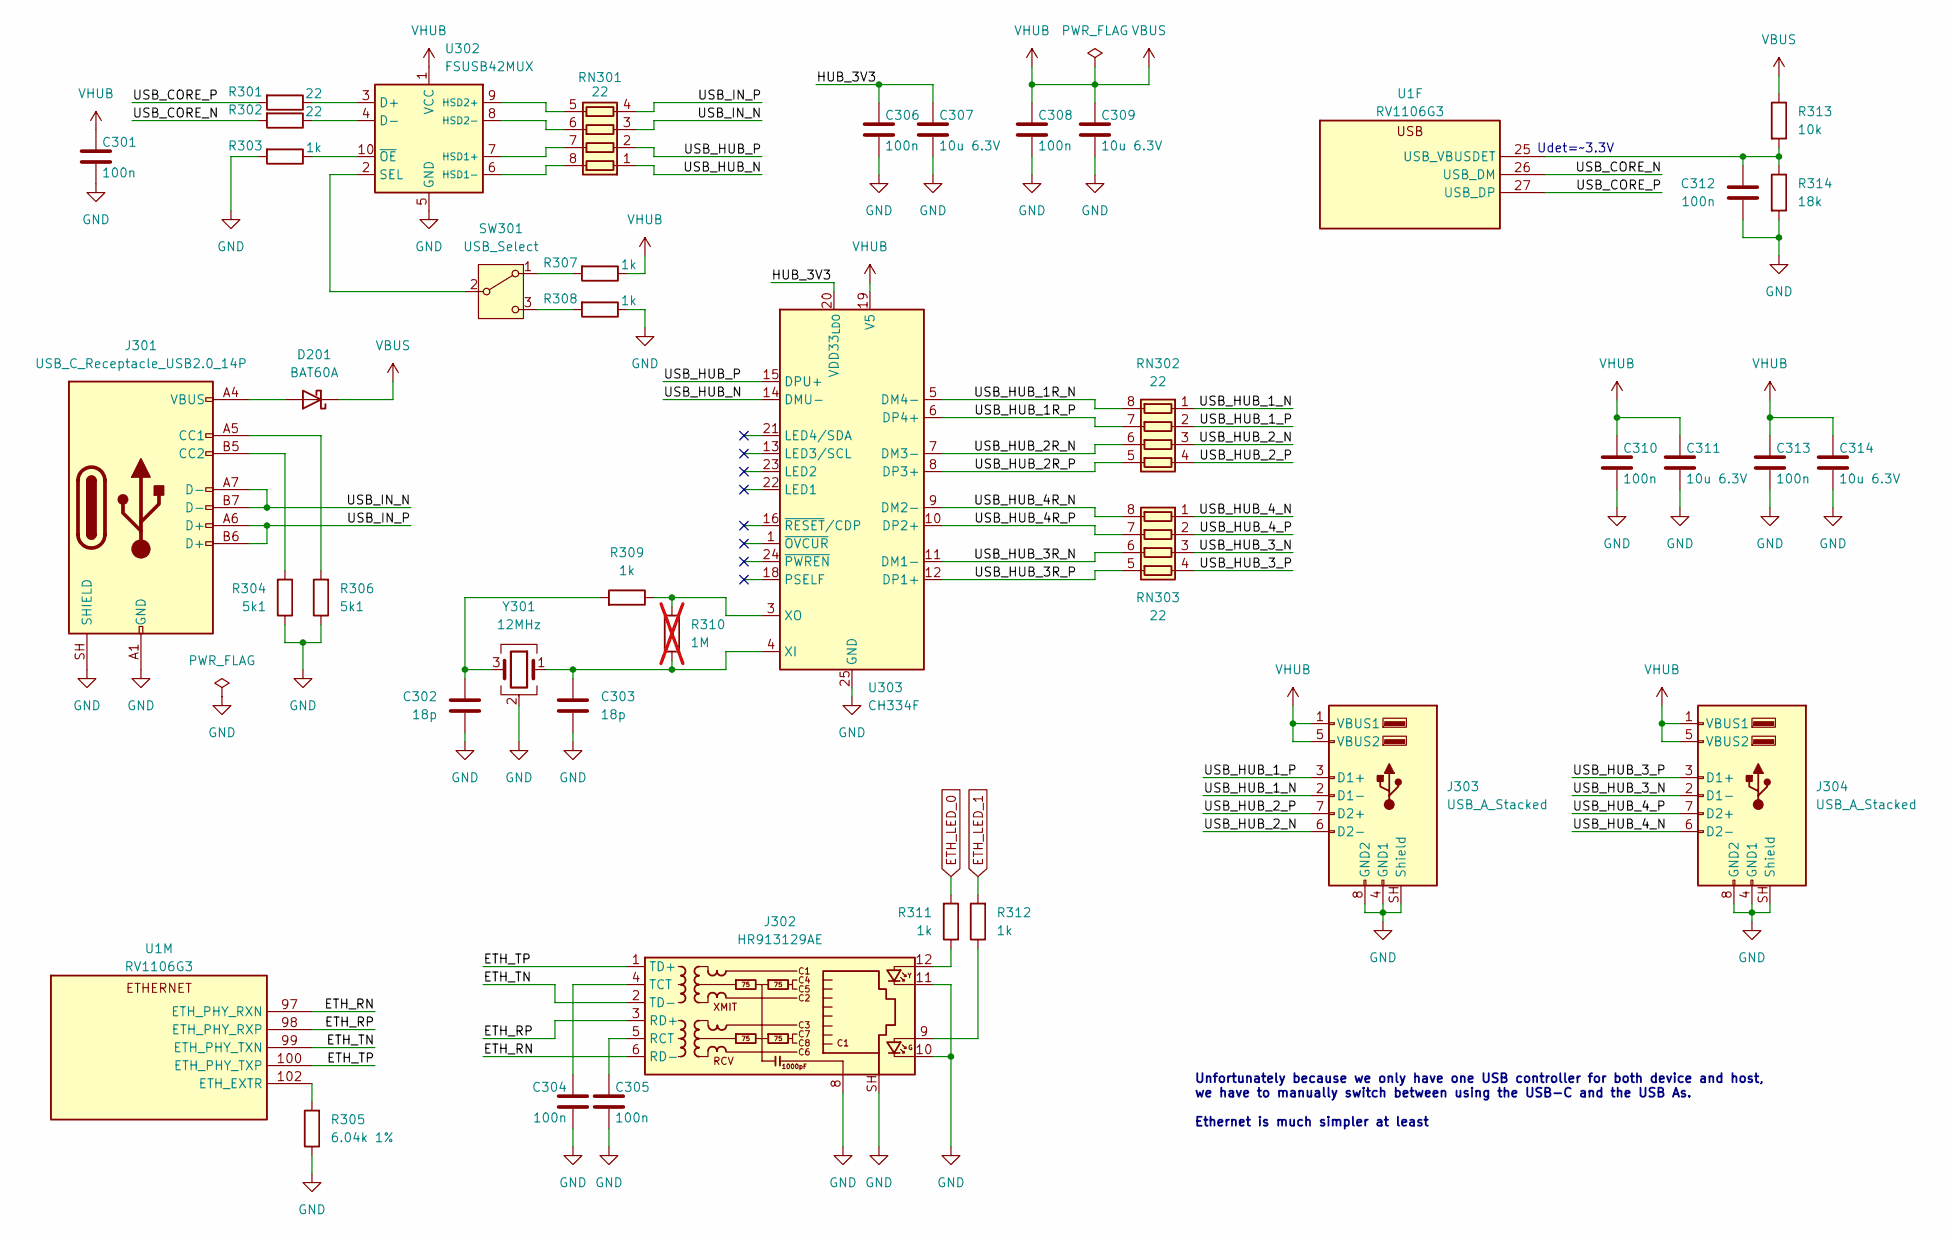
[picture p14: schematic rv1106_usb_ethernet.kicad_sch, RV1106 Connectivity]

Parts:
C301, C304, C305, C306, C308, C310, C312, C313: 100n; C_0402_1005Metric; LCSC C3839219
C302, C303: 18p; C_0402_1005Metric; LCSC C7393840
C307, C309, C311, C314: 10u 6.3V; C_0603_1608Metric; LCSC C1691
D201: BAT60A; D_SOD-323; LCSC C5355496
J301: USB_C_Receptacle_USB2.0_14P; USB_C_Receptacle_G-Switch_GT-USB-7010ASV
J302: HR913129AE; RJ45_Hanrun_HR911105A_Horizontal; LCSC C95663
J303, J304: USB_A_Stacked; USB_A_Wuerth_61400826021_Horizontal_Stacked; LCSC C456021
R301, R302: 22; R_0402_1005Metric; LCSC C2929994
R303, R307, R308, R309, R311, R312: 1k; R_0402_1005Metric; LCSC C54531013
R304, R306: 5k1; R_0402_1005Metric; LCSC C53224182
R305: 6.04k 1%; R_0402_1005Metric; LCSC C881060
R310: 1M; R_0402_1005Metric; not fitted
R313: 10k; R_0402_1005Metric; LCSC C54531014
R314: 18k; R_0402_1005Metric; LCSC C49653003
RN301, RN302, RN303: 22; R_Array_Convex_4x0402; LCSC C168184
SW301: USB_Select; SW_SPDT_PCM12
U1: RV1106G3; Rockchip_QFN-128-1EP_12.3x12.3mm_P0.35mm_EP7x7mm
U302: FSUSB42MUX; MSOP-10_3x3mm_P0.5mm; LCSC C11355
U303: CH334F; QFN-24-1EP_4x4mm_P0.5mm_EP2.7x2.7mm; LCSC C5187527
Y301: 12MHz; Crystal_SMD_2520-4Pin_2.5x2.0mm; LCSC C5261113

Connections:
/USB and Ethernet/ETH_RN: J302.6 (RD-), U1.97 (ETH_PHY_RXN)
/USB and Ethernet/ETH_RP: J302.3 (RD+), U1.98 (ETH_PHY_RXP)
/USB and Ethernet/ETH_TN: J302.2 (TD-), U1.99 (ETH_PHY_TXN)
/USB and Ethernet/ETH_TP: J302.1 (TD+), U1.100 (ETH_PHY_TXP)
/USB and Ethernet/HUB_3V3: C306.1, C307.1, U303.20 (VDD33_{LDO})
/USB and Ethernet/USB_CORE_N: R302.2, U1.26 (USB_DM)
/USB and Ethernet/USB_CORE_P: R301.2, U1.27 (USB_DP)
/USB and Ethernet/USB_HUB_1R_N: RN302.8 (R1.2), U303.5 (DM4-)
/USB and Ethernet/USB_HUB_1R_P: RN302.7 (R2.2), U303.6 (DP4+)
/USB and Ethernet/USB_HUB_1_N: J303.2 (D1-), RN302.1 (R1.1)
/USB and Ethernet/USB_HUB_1_P: J303.3 (D1+), RN302.2 (R2.1)
/USB and Ethernet/USB_HUB_2R_N: RN302.6 (R3.2), U303.7 (DM3-)
/USB and Ethernet/USB_HUB_2R_P: RN302.5 (R4.2), U303.8 (DP3+)
/USB and Ethernet/USB_HUB_2_N: J303.6 (D2-), RN302.3 (R3.1)
/USB and Ethernet/USB_HUB_2_P: J303.7 (D2+), RN302.4 (R4.1)
/USB and Ethernet/USB_HUB_3R_N: RN303.6 (R3.2), U303.11 (DM1-)
/USB and Ethernet/USB_HUB_3R_P: RN303.5 (R4.2), U303.12 (DP1+)
/USB and Ethernet/USB_HUB_3_N: J304.2 (D1-), RN303.3 (R3.1)
/USB and Ethernet/USB_HUB_3_P: J304.3 (D1+), RN303.4 (R4.1)
/USB and Ethernet/USB_HUB_4R_N: RN303.8 (R1.2), U303.9 (DM2-)
/USB and Ethernet/USB_HUB_4R_P: RN303.7 (R2.2), U303.10 (DP2+)
/USB and Ethernet/USB_HUB_4_N: J304.6 (D2-), RN303.1 (R1.1)
/USB and Ethernet/USB_HUB_4_P: J304.7 (D2+), RN303.2 (R2.1)
/USB and Ethernet/USB_HUB_N: RN301.1 (R1.1), U303.14 (DMU-)
/USB and Ethernet/USB_HUB_P: RN301.2 (R2.1), U303.15 (DPU+)
/USB and Ethernet/USB_IN_N: J301.A7 (D-), J301.B7 (D-), RN301.3 (R3.1)
/USB and Ethernet/USB_IN_P: J301.A6 (D+), J301.B6 (D+), RN301.4 (R4.1)
ETH_LED_0: R311.2; also elsewhere on the board
ETH_LED_1: R312.2; also elsewhere on the board
GND: C301.2, C302.2, C303.2, C304.2, C305.2, C306.2, C307.2, C308.2, C309.2, C310.2, C311.2, C312.2, C313.2, C314.2, J301.A1 (GND), J301.A12 (GND), J301.B1 (GND), J301.B12 (GND), J301.SH (SHIELD), J302.8, J302.10, J302.11, J302.SH, J303.4 (GND1), J303.8 (GND2), J303.SH (Shield), J304.4 (GND1), J304.8 (GND2), J304.SH (Shield), R303.2, R304.1, R305.1, R306.1, R308.1, R314.2, U302.5 (GND), U303.25 (GND), Y301.2 (G), Y301.4 (G); also elsewhere on the board
unnamed: C302.1, R309.2, Y301.3
unnamed: D201.2 (A), J301.A4 (VBUS), J301.A9 (VBUS), J301.B4 (VBUS), J301.B9 (VBUS)
unnamed: J301.A5 (CC1), R306.2
unnamed: J301.B5 (CC2), R304.2
unnamed: J302.9, R312.1
unnamed: J302.12, R311.1
unnamed: C305.1, J302.5 (RCT)
unnamed: C304.1, J302.4 (TCT)
unnamed: RN301.8 (R1.2), U302.6 (HSD1-)
unnamed: RN301.7 (R2.2), U302.7 (HSD1+)
unnamed: RN301.6 (R3.2), U302.8 (HSD2-)
unnamed: RN301.5 (R4.2), U302.9 (HSD2+)
unnamed: R307.2, SW301.1 (A)
unnamed: SW301.2 (B), U302.2 (SEL)
unnamed: R308.2, SW301.3 (C)
unnamed: C312.1, R313.2, R314.1, U1.25 (USB_VBUSDET)
unnamed: R305.2, U1.102 (ETH_EXTR)
unnamed: R301.1, U302.3 (D+)
unnamed: R302.1, U302.4 (D-)
unnamed: R303.1, U302.10 (~OE)
unnamed: C303.1, R310.1, U303.4 (XI), Y301.1
unnamed: R309.1, R310.2, U303.3 (XO)
VBUS: C301.1, C308.1, C309.1, C310.1, C311.1, C313.1, C314.1, D201.1 (K), J303.1 (VBUS1), J303.5 (VBUS2), J304.1 (VBUS1), J304.5 (VBUS2), R307.1, R313.1, U302.1 (VCC), U303.19 (V5); also elsewhere on the board

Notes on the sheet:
Udet=~3.3V
Unfortunately because we only have one USB controller for both device and host, we have to manually switch between using the USB-C and the USB As. Ethernet is much simpler at least

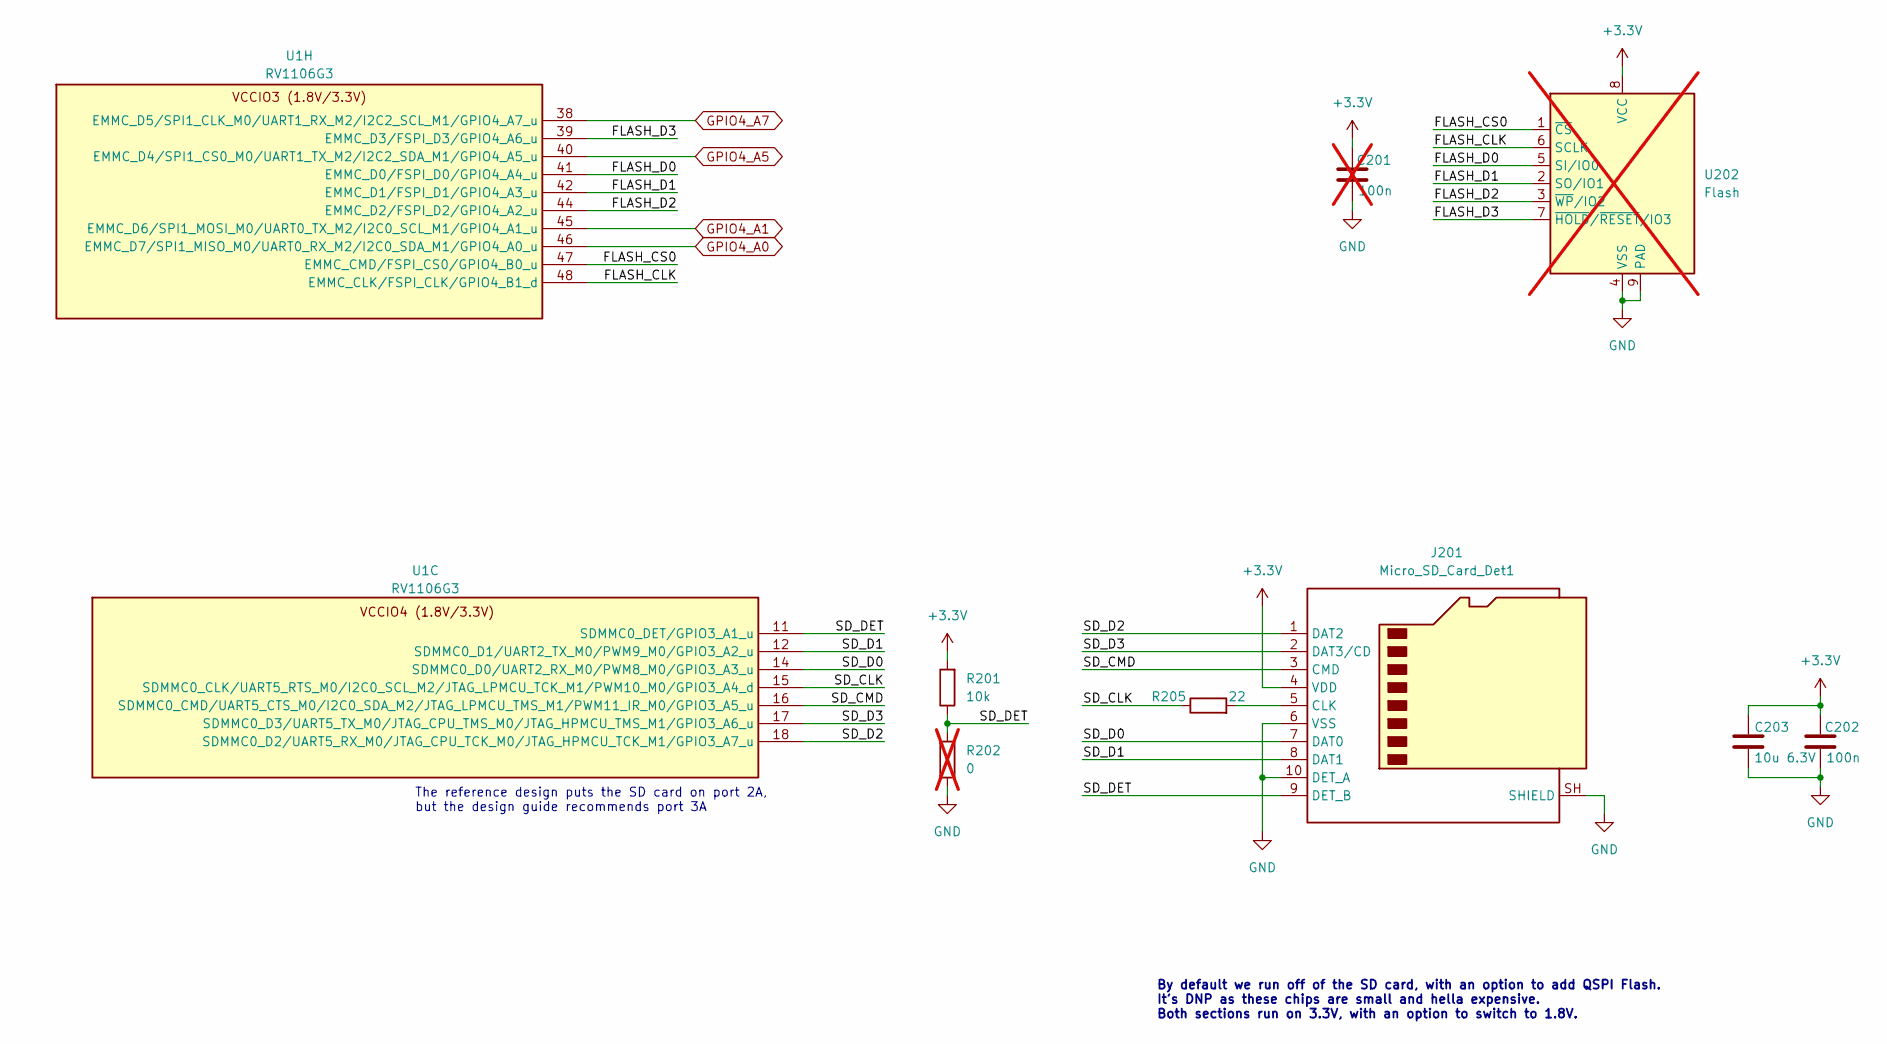
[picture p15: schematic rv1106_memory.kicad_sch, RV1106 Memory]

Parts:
C201: 100n; C_0402_1005Metric; LCSC C3839219; not fitted
C202: 100n; C_0402_1005Metric; LCSC C3839219
C203: 10u 6.3V; C_0603_1608Metric; LCSC C1691
J201: Micro_SD_Card_Det1; microSD_HC_Hirose_DM3D-SF; LCSC C719027
R201: 10k; R_0402_1005Metric; LCSC C54531014
R202: 0; R_0402_1005Metric; not fitted
R205: 22; R_0402_1005Metric; LCSC C2929994
U1: RV1106G3; Rockchip_QFN-128-1EP_12.3x12.3mm_P0.35mm_EP7x7mm
U202: Flash; WSON-8-1EP_8x6mm_P1.27mm_EP3.4x4.3mm; not fitted

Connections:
+3.3V: C201.1, C202.1, C203.1, J201.4 (VDD), R201.2, U202.8 (VCC); also elsewhere on the board
/Memory/FLASH_CLK: U1.48 (EMMC_CLK/FSPI_CLK/GPIO4_B1_d), U202.6 (SCLK)
/Memory/FLASH_CS0: U1.47 (EMMC_CMD/FSPI_CS0/GPIO4_B0_u), U202.1 (~CS)
/Memory/FLASH_D0: U1.41 (EMMC_D0/FSPI_D0/GPIO4_A4_u), U202.5 (SI/IO0)
/Memory/FLASH_D1: U1.42 (EMMC_D1/FSPI_D1/GPIO4_A3_u), U202.2 (SO/IO1)
/Memory/FLASH_D2: U1.44 (EMMC_D2/FSPI_D2/GPIO4_A2_u), U202.3 (~WP/IO2)
/Memory/FLASH_D3: U1.39 (EMMC_D3/FSPI_D3/GPIO4_A6_u), U202.7 (~HOLD/~RESET/IO3)
/Memory/SD_CLK: R205.1, U1.15 (SDMMC0_CLK/UART5_RTS_M0/I2C0_SCL_M2/JTA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)
/Memory/SD_CMD: J201.3 (CMD), U1.16 (SDMMC0_CMD/UART5_CTS_M0/I2C0_SDA_M2/JTA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)
/Memory/SD_D0: J201.7 (DAT0), U1.14 (SDMMC0_D0/UART2_RX_M0/PWM8_M0/GPIO3_A3_u)
/Memory/SD_D1: J201.8 (DAT1), U1.12 (SDMMC0_D1/UART2_TX_M0/PWM9_M0/GPIO3_A2_u)
/Memory/SD_D2: J201.1 (DAT2), U1.18 (SDMMC0_D2/UART5_RX_M0/JTAG_CPU_TCK_M0/J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)
/Memory/SD_D3: J201.2 (DAT3/CD), U1.17 (SDMMC0_D3/UART5_TX_M0/JTAG_CPU_TMS_M0/J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)
/Memory/SD_DET: J201.9 (DET_B), R201.1, R202.2, U1.11 (SDMMC0_DET/GPIO3_A1_u)
GND: C201.2, C202.2, C203.2, J201.6 (VSS), J201.10 (DET_A), J201.SH (SHIELD), R202.1, U202.4 (VSS), U202.9 (PAD); also elsewhere on the board
GPIO4_A0: U1.46 (EMMC_D7/SPI1_MISO_M0/UART0_RX_M2/I2C0_S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); also elsewhere on the board
GPIO4_A1: U1.45 (EMMC_D6/SPI1_MOSI_M0/UART0_TX_M2/I2C0_S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); also elsewhere on the board
GPIO4_A5: U1.40 (EMMC_D4/SPI1_CS0_M0/UART1_TX_M2/I2C2_SD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); also elsewhere on the board
GPIO4_A7: U1.38 (EMMC_D5/SPI1_CLK_M0/UART1_RX_M2/I2C2_SC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); also elsewhere on the board
unnamed: J201.5 (CLK), R205.2

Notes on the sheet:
By default we run off of the SD card, with an option to add QSPI Flash. It's DNP as these chips are small and hella expensive. Both sections run on 3.3V, with an option to switch to 1.8V.
The reference design puts the SD card on port 2A, but the design guide recommends port 3A

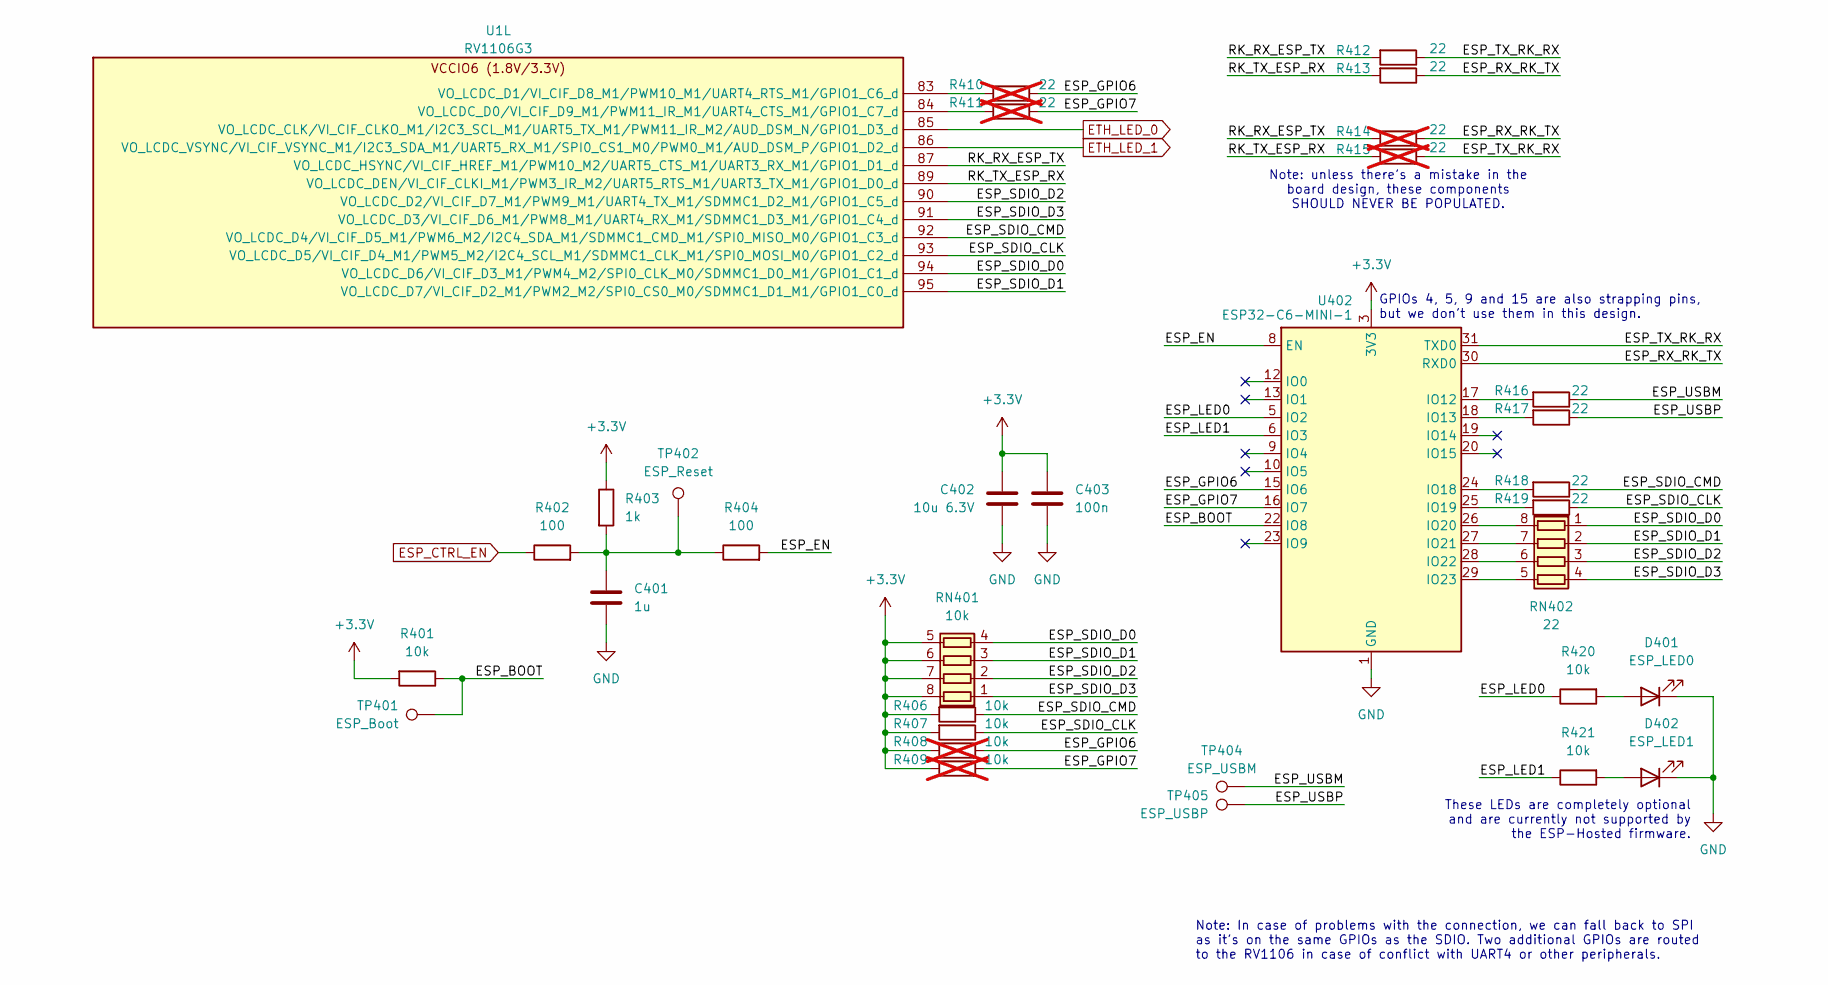
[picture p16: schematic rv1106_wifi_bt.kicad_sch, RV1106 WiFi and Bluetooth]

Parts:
C401: 1u; C_0402_1005Metric; LCSC C380293
C402: 10u 6.3V; C_0603_1608Metric; LCSC C1691
C403: 100n; C_0402_1005Metric; LCSC C3839219
D401: ESP_LED0; LED_0603_1608Metric
D402: ESP_LED1; LED_0603_1608Metric
R401, R406, R407, R420, R421: 10k; R_0402_1005Metric; LCSC C54531014
R402, R404: 100; R_0402_1005Metric; LCSC C54920716
R403: 1k; R_0402_1005Metric; LCSC C54531013
R408, R409: 10k; R_0402_1005Metric; not fitted
R410, R411, R414, R415: 22; R_0402_1005Metric; not fitted
R412, R413, R416, R417, R418, R419: 22; R_0402_1005Metric; LCSC C2929994
RN401: 10k; R_Array_Convex_4x0402; LCSC C168183
RN402: 22; R_Array_Convex_4x0402; LCSC C168184
TP401: ESP_Boot; TestPoint_Pad_D1.5mm
TP402: ESP_Reset; TestPoint_Pad_D1.5mm
TP404: ESP_USBM; TestPoint_Pad_D2.0mm
TP405: ESP_USBP; TestPoint_Pad_D2.0mm
U1: RV1106G3; Rockchip_QFN-128-1EP_12.3x12.3mm_P0.35mm_EP7x7mm
U402: ESP32-C6-MINI-1

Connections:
+3.3V: C402.1, C403.1, R401.2, R403.1, R406.2, R407.2, R408.2, R409.2, RN401.5 (R4.2), RN401.6 (R3.2), RN401.7 (R2.2), RN401.8 (R1.2), U402.3 (3V3); also elsewhere on the board
/WiFi and Bluetooth/ESP_BOOT: R401.1, TP401.1 (1_1), U402.22 (IO8)
/WiFi and Bluetooth/ESP_EN: R404.2, U402.8 (EN)
/WiFi and Bluetooth/ESP_GPIO6: R408.1, R410.1, U402.15 (IO6)
/WiFi and Bluetooth/ESP_GPIO7: R409.1, R411.1, U402.16 (IO7)
/WiFi and Bluetooth/ESP_LED0: R420.1, U402.5 (IO2)
/WiFi and Bluetooth/ESP_LED1: R421.1, U402.6 (IO3)
/WiFi and Bluetooth/ESP_RX_RK_TX: R413.1, R414.1, U402.30 (RXD0)
/WiFi and Bluetooth/ESP_SDIO_CLK: R407.1, R419.1, U1.93 (VO_LCDC_D5/VI_CIF_D4_M1/PWM5_M2/I2C4_SC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)
/WiFi and Bluetooth/ESP_SDIO_CMD: R406.1, R418.1, U1.92 (VO_LCDC_D4/VI_CIF_D5_M1/PWM6_M2/I2C4_SD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)
/WiFi and Bluetooth/ESP_SDIO_D0: RN401.4 (R4.1), RN402.1 (R1.1), U1.94 (VO_LCDC_D6/VI_CIF_D3_M1/PWM4_M2/SPI0_CL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)
/WiFi and Bluetooth/ESP_SDIO_D1: RN401.3 (R3.1), RN402.2 (R2.1), U1.95 (VO_LCDC_D7/VI_CIF_D2_M1/PWM2_M2/SPI0_CS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)
/WiFi and Bluetooth/ESP_SDIO_D2: RN401.2 (R2.1), RN402.3 (R3.1), U1.90 (VO_LCDC_D2/VI_CIF_D7_M1/PWM9_M1/UART4_T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)
/WiFi and Bluetooth/ESP_SDIO_D3: RN401.1 (R1.1), RN402.4 (R4.1), U1.91 (VO_LCDC_D3/VI_CIF_D6_M1/PWM8_M1/UART4_R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)
/WiFi and Bluetooth/ESP_TX_RK_RX: R412.1, R415.1, U402.31 (TXD0)
/WiFi and Bluetooth/ESP_USBM: R416.1, TP404.1 (1_1)
/WiFi and Bluetooth/ESP_USBP: R417.1, TP405.1 (1_1)
/WiFi and Bluetooth/RK_RX_ESP_TX: R412.2, R414.2, U1.87 (VO_LCDC_HSYNC/VI_CIF_HREF_M1/PWM10_M2/U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)
/WiFi and Bluetooth/RK_TX_ESP_RX: R413.2, R415.2, U1.89 (VO_LCDC_DEN/VI_CIF_CLKI_M1/PWM3_IR_M2/U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)
ESP_CTRL_EN: R402.1; also elsewhere on the board
ETH_LED_0: U1.85 (VO_LCDC_CLK/VI_CIF_CLKO_M1/I2C3_SCL_M1/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); also elsewhere on the board
ETH_LED_1: U1.86 (VO_LCDC_VSYNC/VI_CIF_VSYNC_M1/I2C3_SDA_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); also elsewhere on the board
GND: C401.2, C402.2, C403.2, D401.1 (K), D402.1 (K), U402.1 (GND), U402.2 (GND), U402.11 (GND), U402.14 (GND), U402.36 (GND), U402.37 (GND), U402.38 (GND), U402.39 (GND), U402.40 (GND), U402.41 (GND), U402.42 (GND), U402.43 (GND), U402.44 (GND), U402.45 (GND), U402.46 (GND), U402.47 (GND), U402.48 (GND), U402.49 (GND), U402.50 (GND), U402.51 (GND), U402.52 (GND), U402.53 (GND); also elsewhere on the board
unnamed: C401.1, R402.2, R403.2, R404.1, TP402.1 (1_1)
unnamed: D401.2 (A), R420.2
unnamed: D402.2 (A), R421.2
unnamed: RN402.8 (R1.2), U402.26 (IO20)
unnamed: RN402.7 (R2.2), U402.27 (IO21)
unnamed: RN402.6 (R3.2), U402.28 (IO22)
unnamed: RN402.5 (R4.2), U402.29 (IO23)
unnamed: R411.2, U1.84 (VO_LCDC_D0/VI_CIF_D9_M1/PWM11_IR_M1/UAR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)
unnamed: R410.2, U1.83 (VO_LCDC_D1/VI_CIF_D8_M1/PWM10_M1/UART4_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)
unnamed: R416.2, U402.17 (IO12)
unnamed: R417.2, U402.18 (IO13)
unnamed: R418.2, U402.24 (IO18)
unnamed: R419.2, U402.25 (IO19)

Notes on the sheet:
These LEDs are completely optional and are currently not supported by the ESP-Hosted firmware.
Note: In case of problems with the connection, we can fall back to SPI as it's on the same GPIOs as the SDIO. Two additional GPIOs are routed to the RV1106 in case of conflict with UART4 or other peripherals.
Note: unless there's a mistake in the board design, these components SHOULD NEVER BE POPULATED.
GPIOs 4, 5, 9 and 15 are also strapping pins, but we don't use them in this design.

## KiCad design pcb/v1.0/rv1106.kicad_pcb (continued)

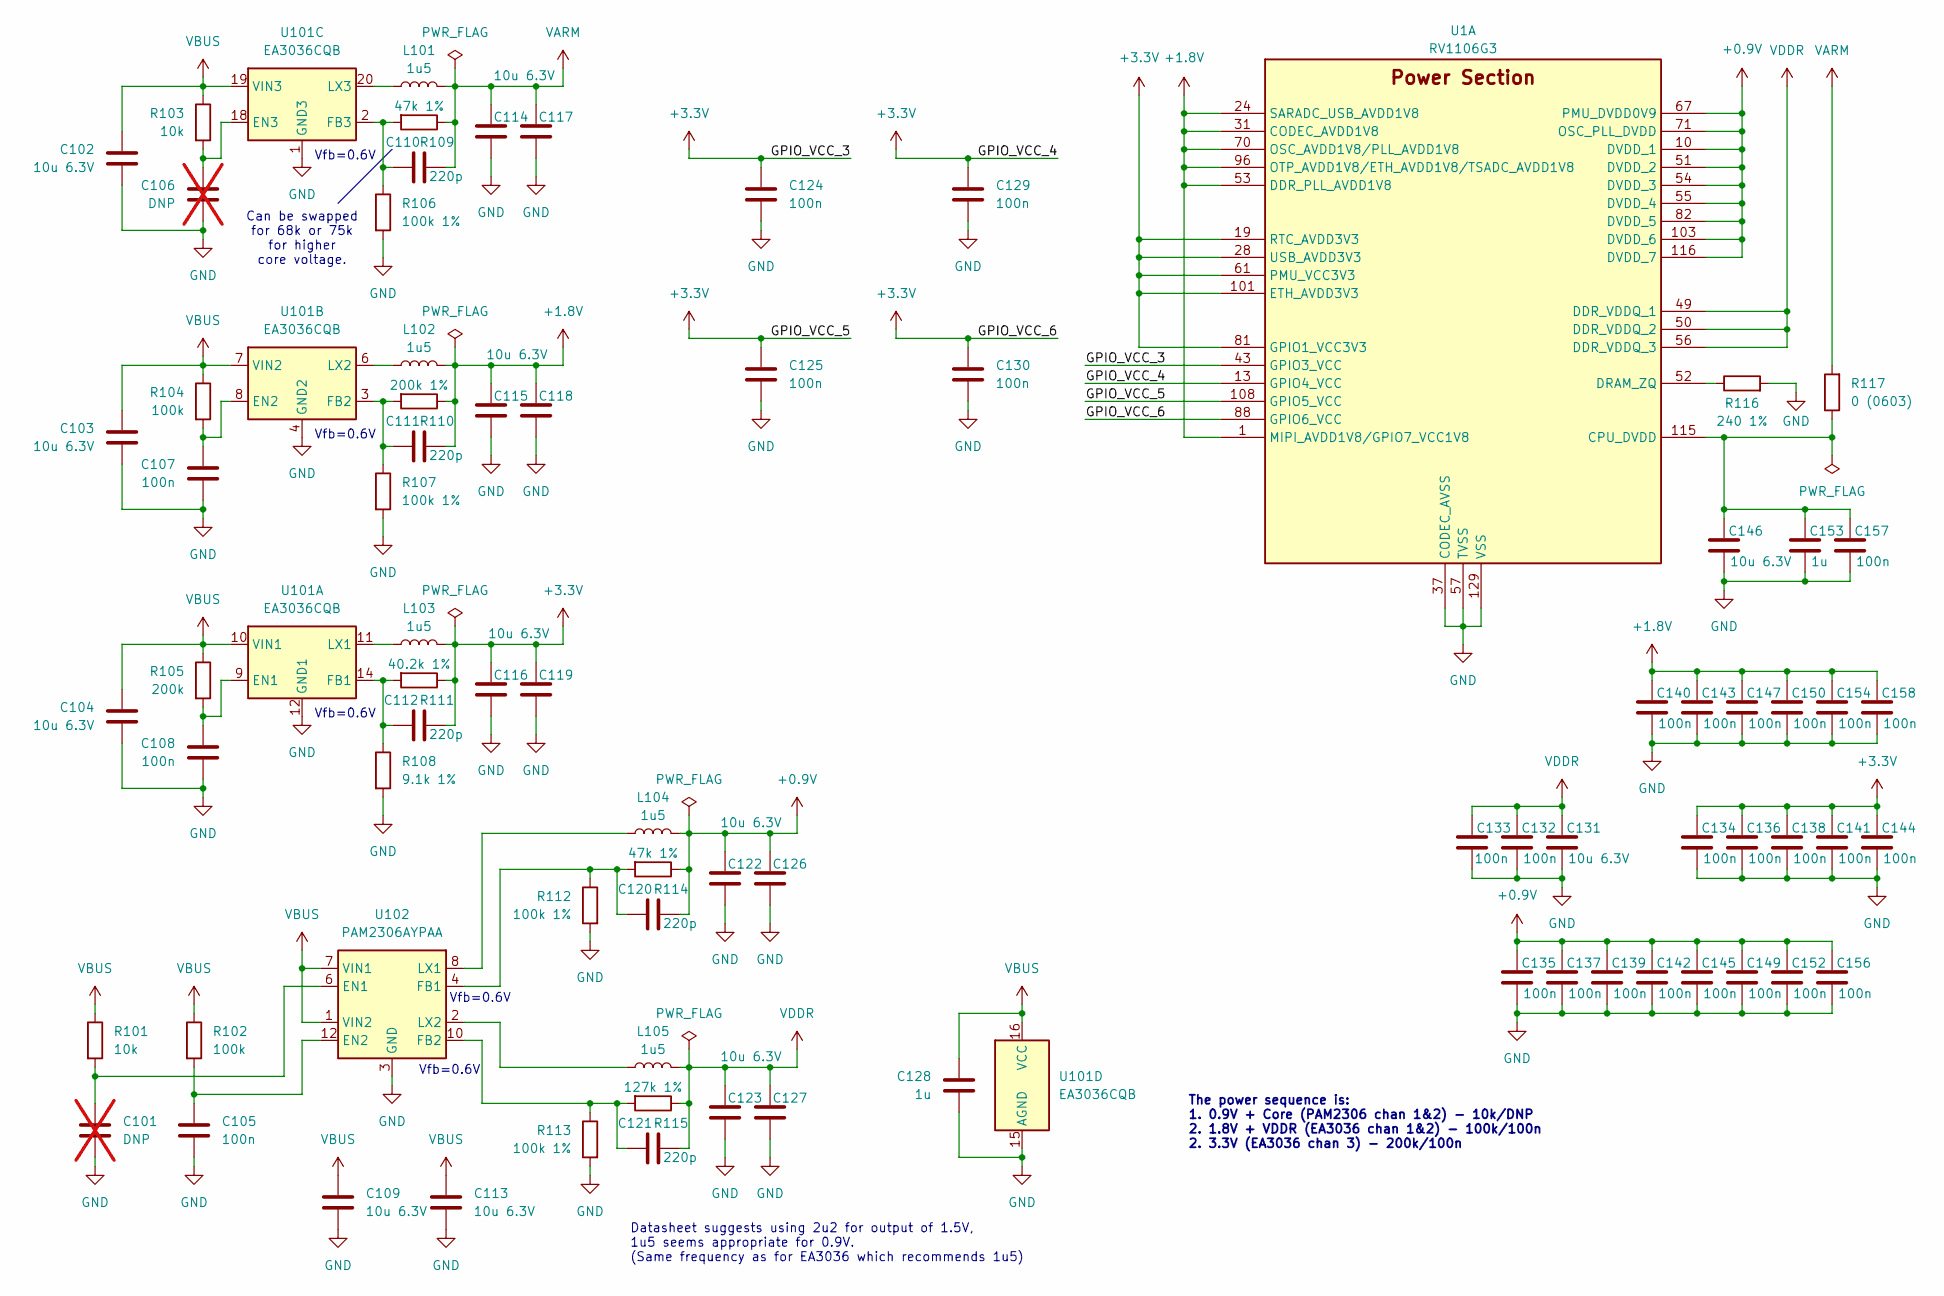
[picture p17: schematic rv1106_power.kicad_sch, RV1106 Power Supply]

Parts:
C101, C106: DNP; C_0402_1005Metric; not fitted
C102, C103, C104, C109, C113, C114, C115, C116, C117, C118, C119, C122, C123, C126, C127, C131, C146: 10u 6.3V; C_0603_1608Metric; LCSC C1691
C105, C107, C108, C124, C125, C129, C130, C132, C133, C134, C135, C136, C137, C138, C139, C140, C141, C142, C143, C144, C145, C147, C149, C150, C152, C154, C156, C157, C158: 100n; C_0402_1005Metric; LCSC C3839219
C110, C111, C112, C120, C121: 220p; C_0402_1005Metric; LCSC C50323515
C128, C153: 1u; C_0402_1005Metric; LCSC C380293
L101, L102, L103, L104, L105: 1u5; L_1008_2520Metric; LCSC C53514831
R101, R103: 10k; R_0402_1005Metric; LCSC C54531014
R102, R104: 100k; R_0402_1005Metric; LCSC C53224176
R105: 200k; R_0402_1005Metric; LCSC C54920643
R106, R107, R112, R113: 100k 1%; R_0402_1005Metric; LCSC C53224176
R108: 9.1k 1%; R_0402_1005Metric; LCSC C54920711
R109, R114: 47k 1%; R_0402_1005Metric; LCSC C18222281
R110: 200k 1%; R_0402_1005Metric; LCSC C54920643
R111: 40.2k 1%; R_0402_1005Metric; LCSC C25893
R115: 127k 1%; R_0402_1005Metric; LCSC C48391434
R116: 240 1%; R_0402_1005Metric; LCSC C2909339
R117: 0 (0603); R_0603_1608Metric; LCSC C53224183
U1: RV1106G3; Rockchip_QFN-128-1EP_12.3x12.3mm_P0.35mm_EP7x7mm
U101: EA3036CQB; QFN-20-1EP_3x3mm_P0.4mm_EP1.65x1.65mm; LCSC C570857
U102: PAM2306AYPAA; WDFN-12-1EP_3x3mm_P0.45mm_EP1.7x2.5mm; LCSC C508237

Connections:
+0.9V: C120.2, C122.2, C126.2, C135.1, C137.1, C139.1, C142.1, C145.1, C149.1, C152.1, C156.1, L104.2, R114.1, U1.10 (DVDD_1), U1.51 (DVDD_2), U1.54 (DVDD_3), U1.55 (DVDD_4), U1.67 (PMU_DVDD0V9), U1.71 (OSC_PLL_DVDD), U1.82 (DVDD_5), U1.103 (DVDD_6), U1.116 (DVDD_7)
+1.8V: C111.2, C115.2, C118.2, C140.1, C143.1, C147.1, C150.1, C154.1, C158.1, L102.2, R110.1, U1.1 (MIPI_AVDD1V8/GPIO7_VCC1V8), U1.24 (SARADC_USB_AVDD1V8), U1.31 (CODEC_AVDD1V8), U1.53 (DDR_PLL_AVDD1V8), U1.70 (OSC_AVDD1V8/PLL_AVDD1V8), U1.96 (OTP_AVDD1V8/ETH_AVDD1V8/TSADC_AVDD1V8); also elsewhere on the board
+3.3V: C112.2, C116.2, C119.2, C124.1, C125.1, C129.1, C130.1, C134.1, C136.1, C138.1, C141.1, C144.1, L103.2, R111.1, U1.13 (GPIO4_VCC), U1.19 (RTC_AVDD3V3), U1.28 (USB_AVDD3V3), U1.43 (GPIO3_VCC), U1.61 (PMU_VCC3V3), U1.81 (GPIO1_VCC3V3), U1.88 (GPIO6_VCC), U1.101 (ETH_AVDD3V3), U1.108 (GPIO5_VCC); also elsewhere on the board
GND: C101.1, C102.1, C103.1, C104.1, C105.1, C106.1, C107.1, C108.1, C109.1, C113.1, C114.1, C115.1, C116.1, C117.1, C118.1, C119.1, C122.1, C123.1, C124.2, C125.2, C126.1, C127.1, C128.1, C129.2, C130.2, C131.2, C132.2, C133.2, C134.2, C135.2, C136.2, C137.2, C138.2, C139.2, C140.2, C141.2, C142.2, C143.2, C144.2, C145.2, C146.2, C147.2, C149.2, C150.2, C152.2, C153.2, C154.2, C156.2, C157.2, C158.2, R106.2, R107.2, R108.2, R112.2, R113.2, R116.2, U1.37 (CODEC_AVSS), U1.57 (TVSS), U1.129 (VSS), U101.1 (GND3), U101.4 (GND2), U101.5 (GND2), U101.12 (GND1), U101.13 (GND1), U101.15 (AGND), U101.17 (AGND), U101.21 (AGND), U102.3 (GND), U102.9 (GND), U102.13 (GND); also elsewhere on the board
unnamed: C146.1, C153.1, C157.1, R117.1, U1.115 (CPU_DVDD)
unnamed: R116.1, U1.52 (DRAM_ZQ)
unnamed: C108.2, R105.2, U101.9 (EN1)
unnamed: C112.1, R108.1, R111.2, U101.14 (FB1)
unnamed: L103.1, U101.11 (LX1)
unnamed: C107.2, R104.2, U101.8 (EN2)
unnamed: C111.1, R107.1, R110.2, U101.3 (FB2)
unnamed: L102.1, U101.6 (LX2)
unnamed: C106.2, R103.2, U101.18 (EN3)
unnamed: C110.1, R106.1, R109.2, U101.2 (FB3)
unnamed: L101.1, U101.20 (LX3)
unnamed: C101.2, R101.2, U102.6 (EN1)
unnamed: C105.2, R102.2, U102.12 (EN2)
unnamed: C120.1, R112.1, R114.2, U102.4 (FB1)
unnamed: C121.1, R113.1, R115.2, U102.10 (FB2)
unnamed: L104.1, U102.8 (LX1)
unnamed: L105.1, U102.2 (LX2)
VARM: C110.2, C114.2, C117.2, L101.2, R109.1, R117.2
VBUS: C102.2, C103.2, C104.2, C109.2, C113.2, C128.2, R101.1, R102.1, R103.1, R104.1, R105.1, U101.7 (VIN2), U101.10 (VIN1), U101.16 (VCC), U101.19 (VIN3), U102.1 (VIN2), U102.7 (VIN1); also elsewhere on the board
VDDR: C121.2, C123.2, C127.2, C131.1, C132.1, C133.1, L105.2, R115.1, U1.49 (DDR_VDDQ_1), U1.50 (DDR_VDDQ_2), U1.56 (DDR_VDDQ_3)

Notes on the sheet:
Vfb=0.6V
Can be swapped for 68k or 75k for higher core voltage.
The power sequence is: 1. 0.9V + Core (PAM2306 chan 1&2) - 10k/DNP 2. 1.8V + VDDR (EA3036 chan 1&2) - 100k/100n 2. 3.3V (EA3036 chan 3) - 200k/100n
Datasheet suggests using 2u2 for output of 1.5V, 1u5 seems appropriate for 0.9V. (Same frequency as for EA3036 which recommends 1u5)

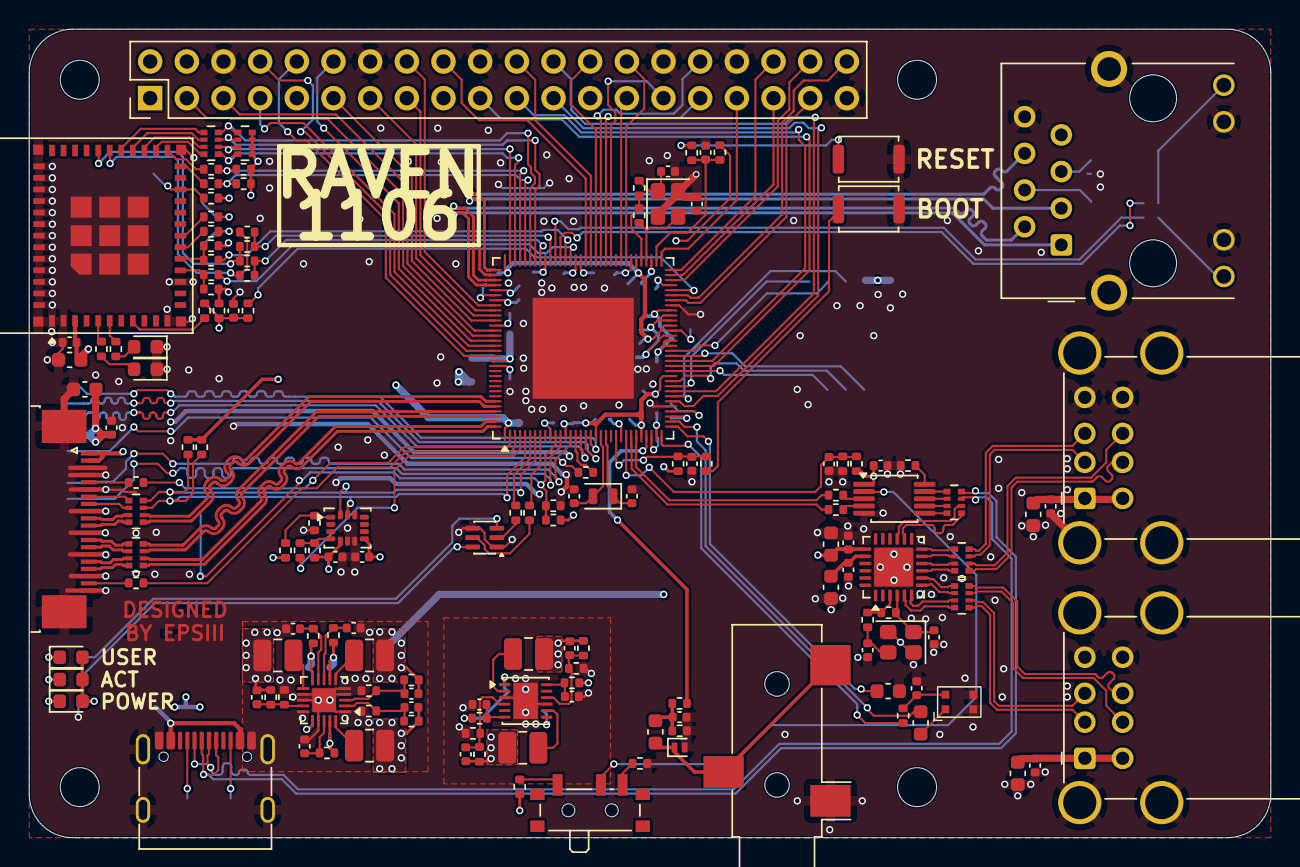
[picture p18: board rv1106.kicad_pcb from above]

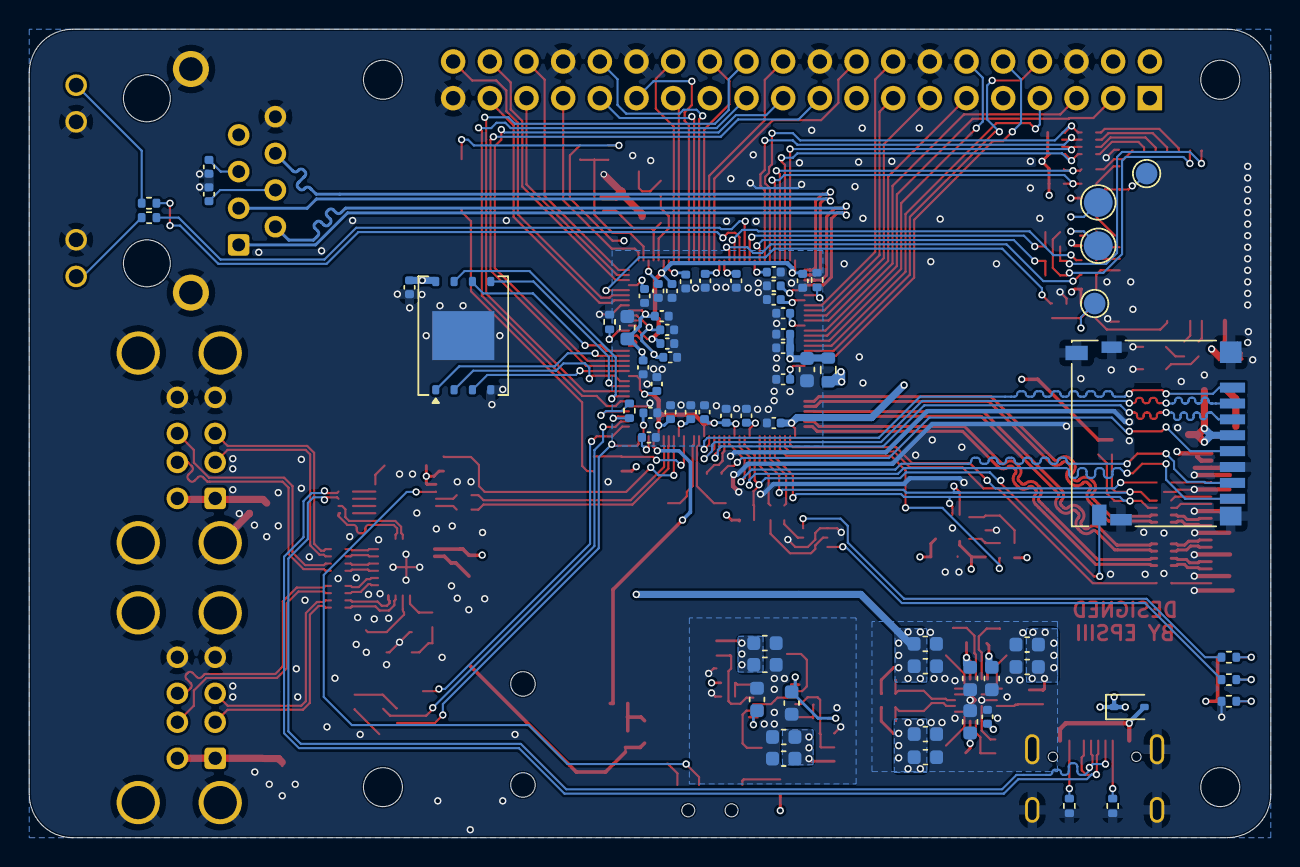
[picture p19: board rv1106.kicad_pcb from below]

Board: 4 copper layers, 86.0 x 56.0 mm, 217 parts (67 on the bottom side), 201 nets.

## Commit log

2026-08-21 feat: Add image build scripts
    [genimage.cfg]
2026-08-21 feat: Improve image build
    [flash-image.cfg, sdcard-image.cfg]
2026-08-22 merge: Merge split build trees (#1)
    Split build into three distinct components:
    * rootfs (buildroot)
    * kernel
    * uboot
    Add crosstool-ng for compiling the BSP components
    Update the env.txt and uboot configs: Machine boots without interaction
    [flash-image.cfg, sdcard-image.cfg]
2026-08-31 cleanup the device tree, copy board files into the repo
    [rv1106.csv, rv1106.kicad_pcb, rv1106.kicad_sch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]
2026-09-04 Fix docker env, add FS-related and camera BR2 packages, fix USB in DT, add auto fs resize (untested)
2026-09-04 Rewrite build scripts, add autoresize to br2 build, add an option for ubuntu build
    [flash-image.cfg]
2026-09-06 Split PCB design into v1 and v1.1 with component updates, change BR2 static ethernet address to DHCP, remove Ubuntu image build (ubuntu sucks)
    [rv1106.csv, rv1106.kicad_pcb, rv1106.kicad_sch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]
2026-09-07 Update docs
    [rv1106.csv, rv1106.kicad_pcb, rv1106.kicad_sch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]
2026-09-19 Move away from buildroot image builder
    [sdcard-image.cfg]
2026-10-04 add options for the ESP to the Device Tree, add markers to the v1.1 schematic
2026-11-01 *finally* get the ESP driver working
